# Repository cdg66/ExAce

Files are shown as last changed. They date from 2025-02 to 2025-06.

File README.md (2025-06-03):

# 📘 Project ExAce





> [!Warning]
>
> Content is not proven and suject to change without notice! Send to fab at your own risk. 

## 🧩 Overview

A tiny yet powerful fpga acceleration card designed with the Framework laptop expansion module system in mind.

## 🛠️ Features

- ✅ [CCGM1A1/2/4 compatible](https://colognechip.com/docs/ds1001-gatemate1-datasheet-latest.pdf)
- ✅ 20,480, 40,960 or 81,920 8-input LUT-trees.
- ✅ USB-type C, 5V 1.5A.
- ✅ Full access to SERDES via the USB-c connector (1 for A1/A2 and 2 for A4 device).
- ✅ USB2.0 interface is shared between the fpga and mcu via a USB mux.
- ✅ STM32L422RBI6 coprocessor and programmer.
- ✅ Shared Earth and i2c between the fpga and microcontroller for easier development.
- ✅ Free and Open-source FPGA toolchain!
- ✅ Lots of sensors!: PDM microphone, 6DoF imu, magnetometer, and thermometer.
- ✅ 8 user programmable led ideal for VU meters.
- ✅ 1 lvds IO ideal for connecting multiple board together in a cluster.
- 🔜 TinyFPGA-Bootloader support TBD.
- 🔜 DirtyJTAG support TBD.

---

## 💪 Application

- ✅ Machine learning
- ✅ Simulation
- ✅ Audio/Signal processing
- ✅ Retro Gaming
- ✅ Development platform

## 🗂️ Repository Structure

```bash
📁 /pcb-project-root
├── /3D_Models                    # 3D models of the PCB rendering
├── /Outputs/Fabrication          # Generated Gerber files, BOM and POS for fabrication
├── /PINOUT                       # STM32CubeMx for reference pinout
├── /Testbench/ExAceTestbench     # Testbench to break out serdes signals
├── /.gitignore
└── README.md
```

---

## 🧰 Tools & Dependencies

- **Design Software:** KiCad (v9.0.2 or higher)
- **MCU/FPGA Programmer:** ST-Link,Pico Dirty JTAG
- **Firmware Toolchain:** STM32CubeMX, arm toolchain, [Colonge chip open source toolchain](https://www.colognechip.com/docs/ug1002-toolchain-install-latest.pdf)  

---

## 🖼️ 3D view

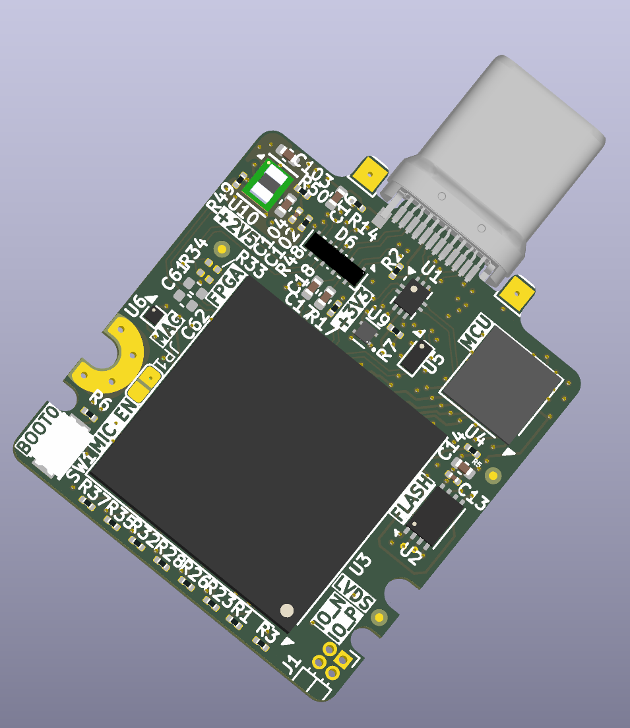
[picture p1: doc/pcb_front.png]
Front
  
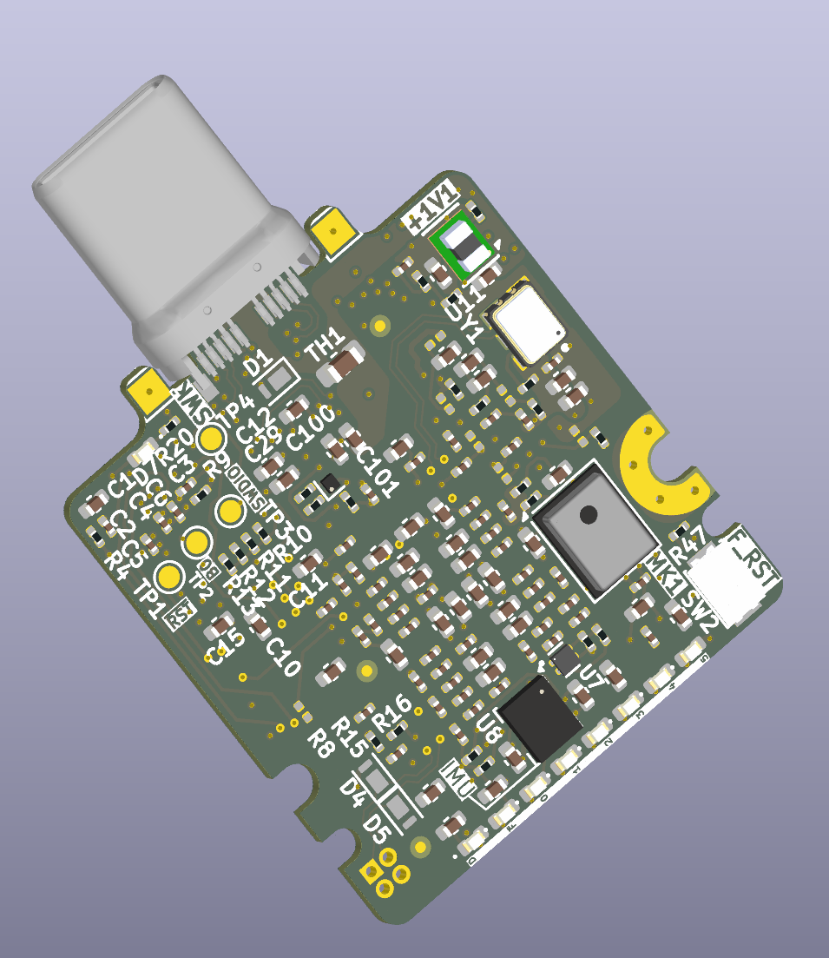
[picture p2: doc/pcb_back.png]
Back


---

## 🏗️ Getting Started

1. **Clone this repository**
   ```bash
   git clone https://github.com/cdg66/ExAce.git
   ```
2. **Open the project** in KiCad (navigate to `Expansion_Card_Retrofit.kicad_pro`)
3. **Modify / Build / Export Gerbers**

---

## 🚀 Fabrication

To get the board fabricated:

- Use the files in the `/Outputs` directory
- Recommended fabs:
  - [NextPcb](https://www.nextpcb.com/)
  - [JLCPCB](https://jlcpcb.com/) 

Stack-up:

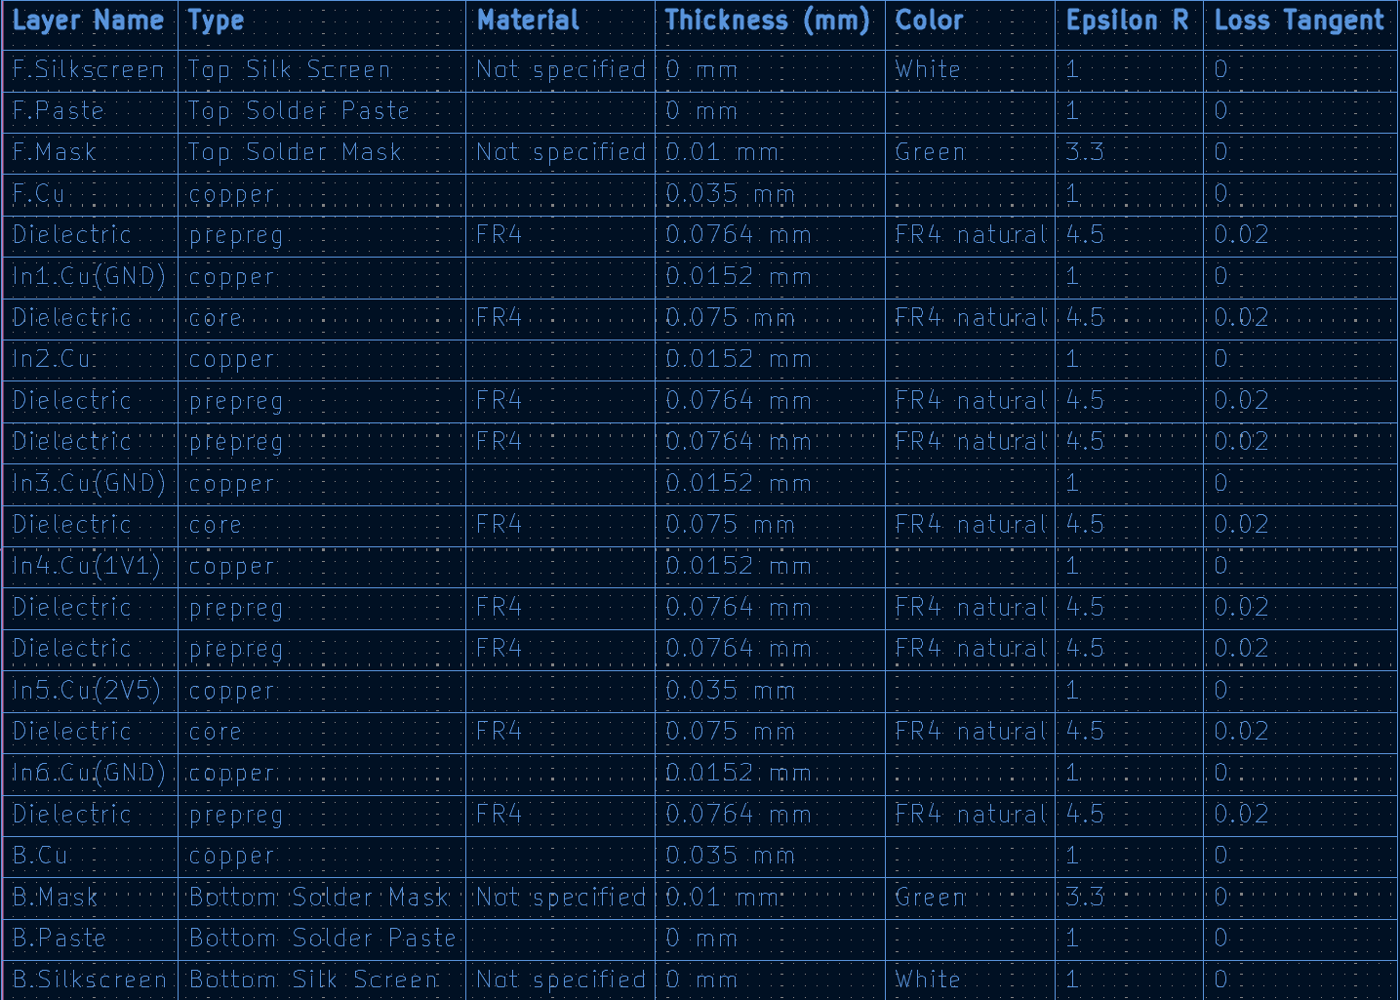
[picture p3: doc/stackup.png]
stackup


The recommended stack up is the JLC08081H-1080A at JLCPCB but can be done at any other PCB manufacturer.

---

## 🔧 License

This work is licensed under a [Creative Commons Attribution 4.0 International License](https://creativecommons.org/licenses/by/4.0/).

This project references and builds upon the open-source designs from  
[FrameworkComputer/ExpansionCards](https://github.com/FrameworkComputer/ExpansionCards),  
which is also licensed under the [Creative Commons Attribution 4.0 International License (CC-BY-4.0)](https://creativecommons.org/licenses/by/4.0/).

TPSM82822SILR

Footprint: Ultralibrarian

3D model: SnapMagic

Edited by me

S3A2505-100.000-L-X1-R

Symbol, Footprint, 3D model: SnapMagic

Edited by me

1054440011

3D model: Molex

KXT_331_LHS

3D model: SnapMagic

STM32L422RBI6

3D model: SnapMagic

TPS7A2033PDQNR

3D model: SnapMagic

---

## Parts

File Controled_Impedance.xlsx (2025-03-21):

Item # | Impedance type | Signal Layer | Reference Layer | Trace Width (mm) | trace Spacing | Required Impedance
1 | differential | Bottom | In1 | 0.09 | 0.3 | 100diff (+-10%)
1 | differential | Top | In6 | 0.09 | 0.3 | 100diff (+-10%)
1 | differential | In2 | In1-In3 | 0.09 | 0.3 | 100diff (+-10%)
1 | differential | Bottom | In1 | 0.1 | 0.2 | 90diff (+-10%)
1 | differential | Top | In6 | 0.1 | 0.2 | 91diff (+-10%)
1 | differential | In2 | In1-In3 | 0.1 | 0.2 | 92diff (+-10%)

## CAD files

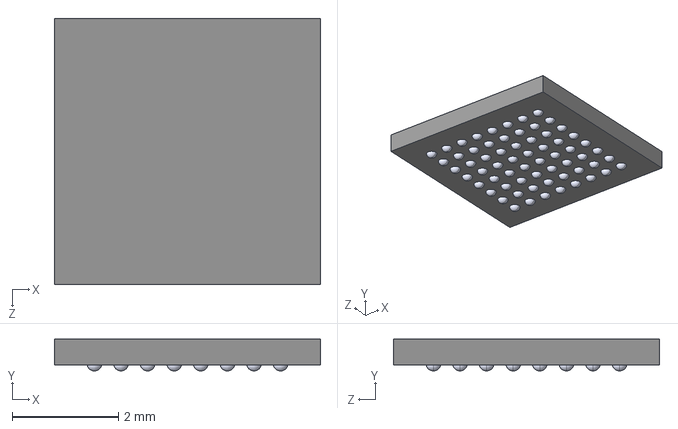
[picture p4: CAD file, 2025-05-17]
3D_Models/STM32L422RBI6.step
5.00 x 0.6 x 5.00 mm

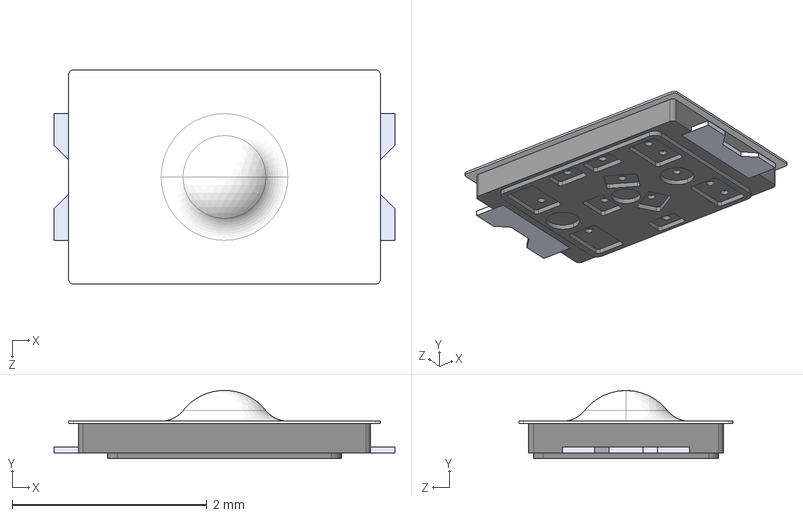
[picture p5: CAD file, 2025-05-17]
3D_Models/KXT_331_LHS.STEP
3.50 x 0.7 x 2.20 mm

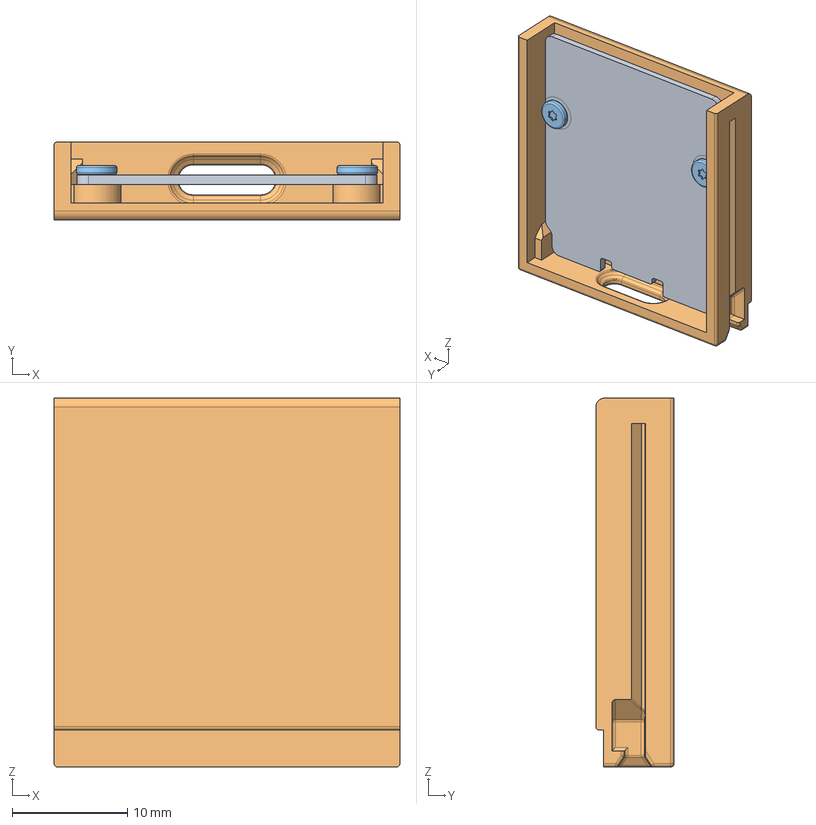
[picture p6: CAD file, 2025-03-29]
3D_Models/ExpansionCard_SelfTapping.stp
30.0 x 6.80 x 32.0 mm
FW_EXP_1USBC_FRAME_CLIP_BC_229_
STAR_SCREW_M2X3L_298_1 x 2

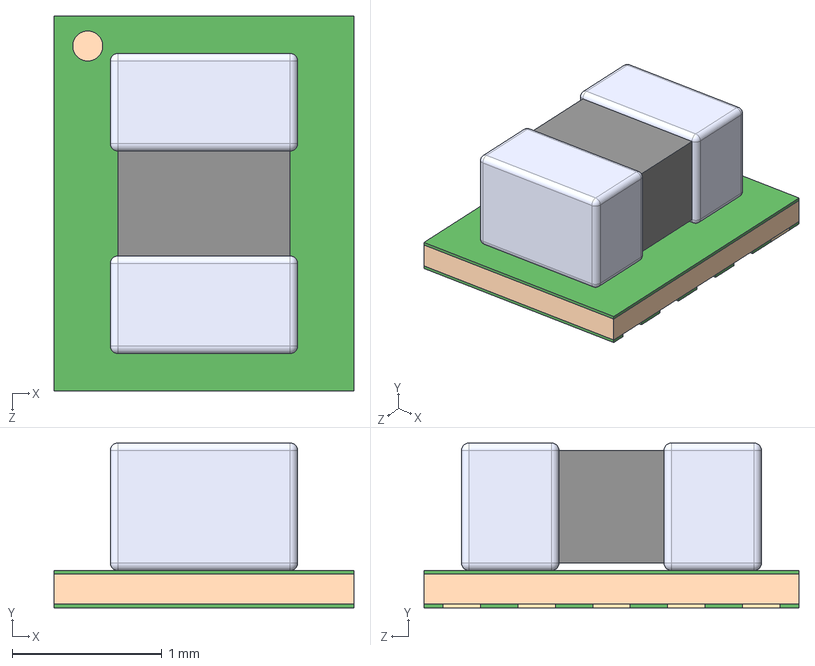
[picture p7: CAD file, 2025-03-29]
3D_Models/TPSM82822SILR.step
2.00 x 1.10 x 2.50 mm

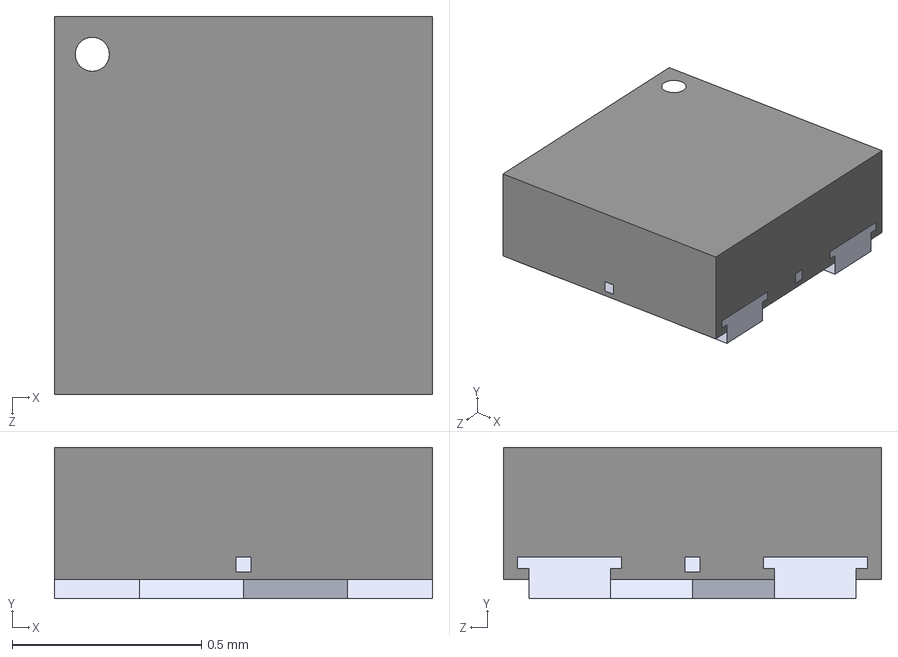
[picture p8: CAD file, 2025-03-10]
3D_Models/TPS7A2033PDQNR.step
1.00 x 0.4 x 1.00 mm

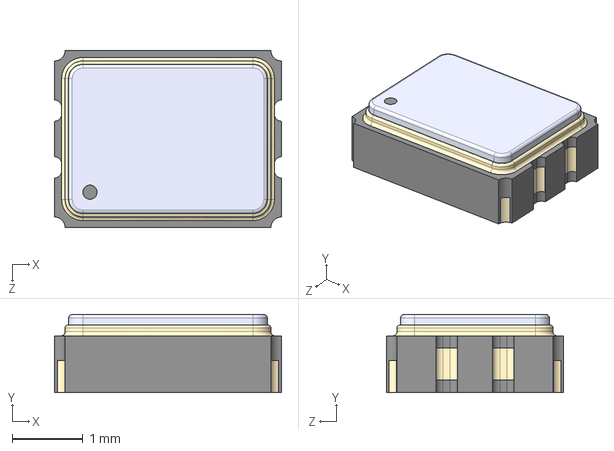
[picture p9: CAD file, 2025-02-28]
3D_Models/S3A2505-100.000-L-X1-R.step
3.20 x 1.10 x 2.50 mm

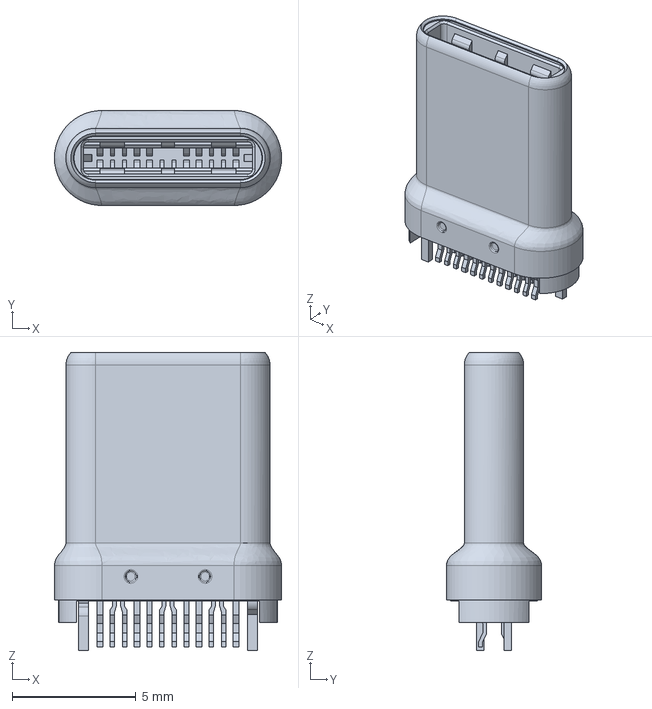
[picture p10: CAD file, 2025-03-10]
3D_Models/1054440011.stp
9.18 x 3.84 x 12.0 mm

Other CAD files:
3D_Models/ExpansionCard_SelfTapping.stl

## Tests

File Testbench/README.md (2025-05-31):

this is asimple board that breakout the SERDES pins out to SMA connectors for easy testing of the interface.

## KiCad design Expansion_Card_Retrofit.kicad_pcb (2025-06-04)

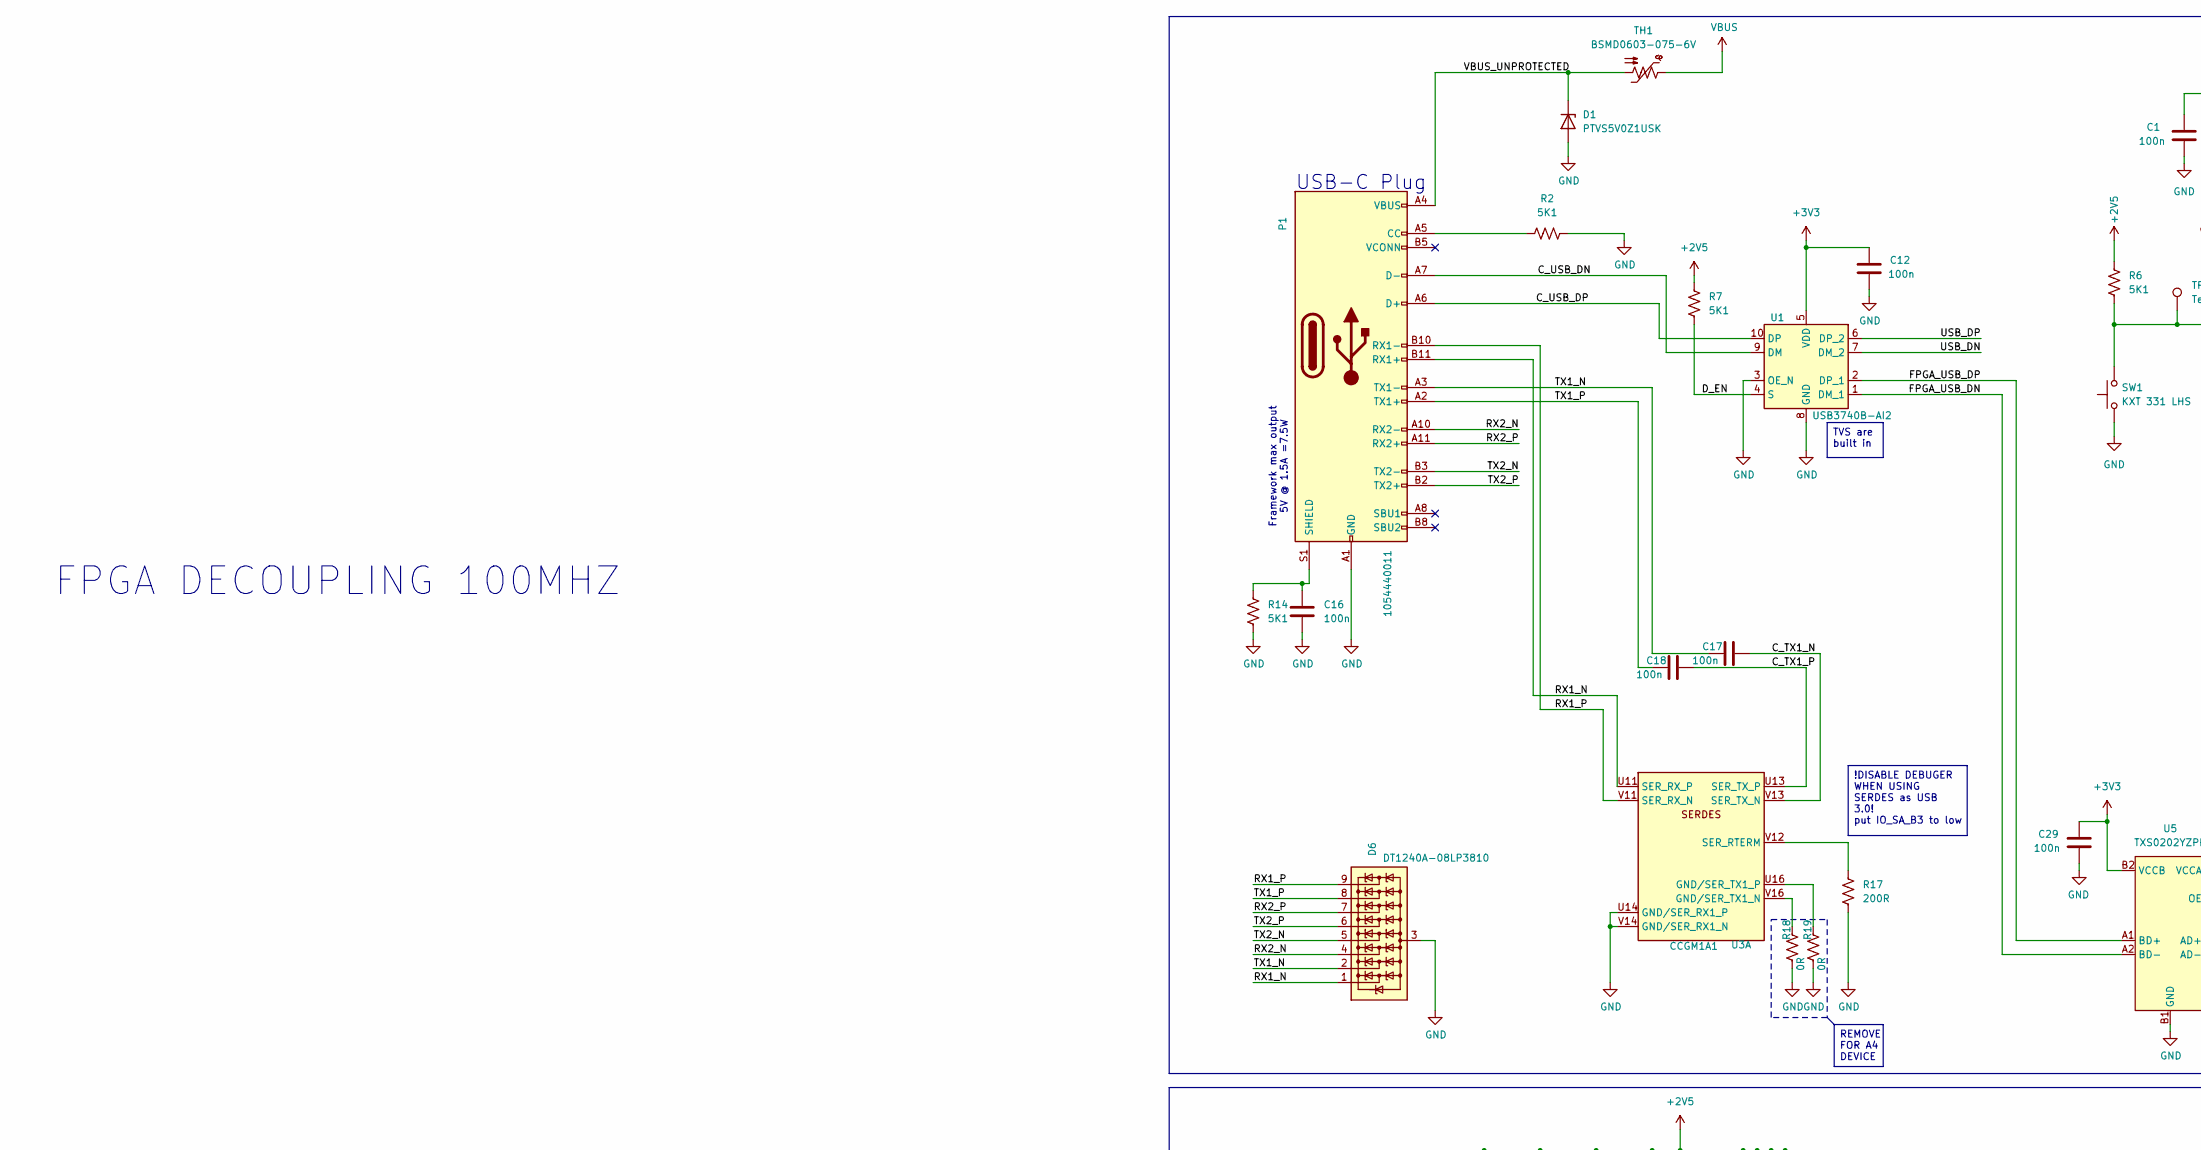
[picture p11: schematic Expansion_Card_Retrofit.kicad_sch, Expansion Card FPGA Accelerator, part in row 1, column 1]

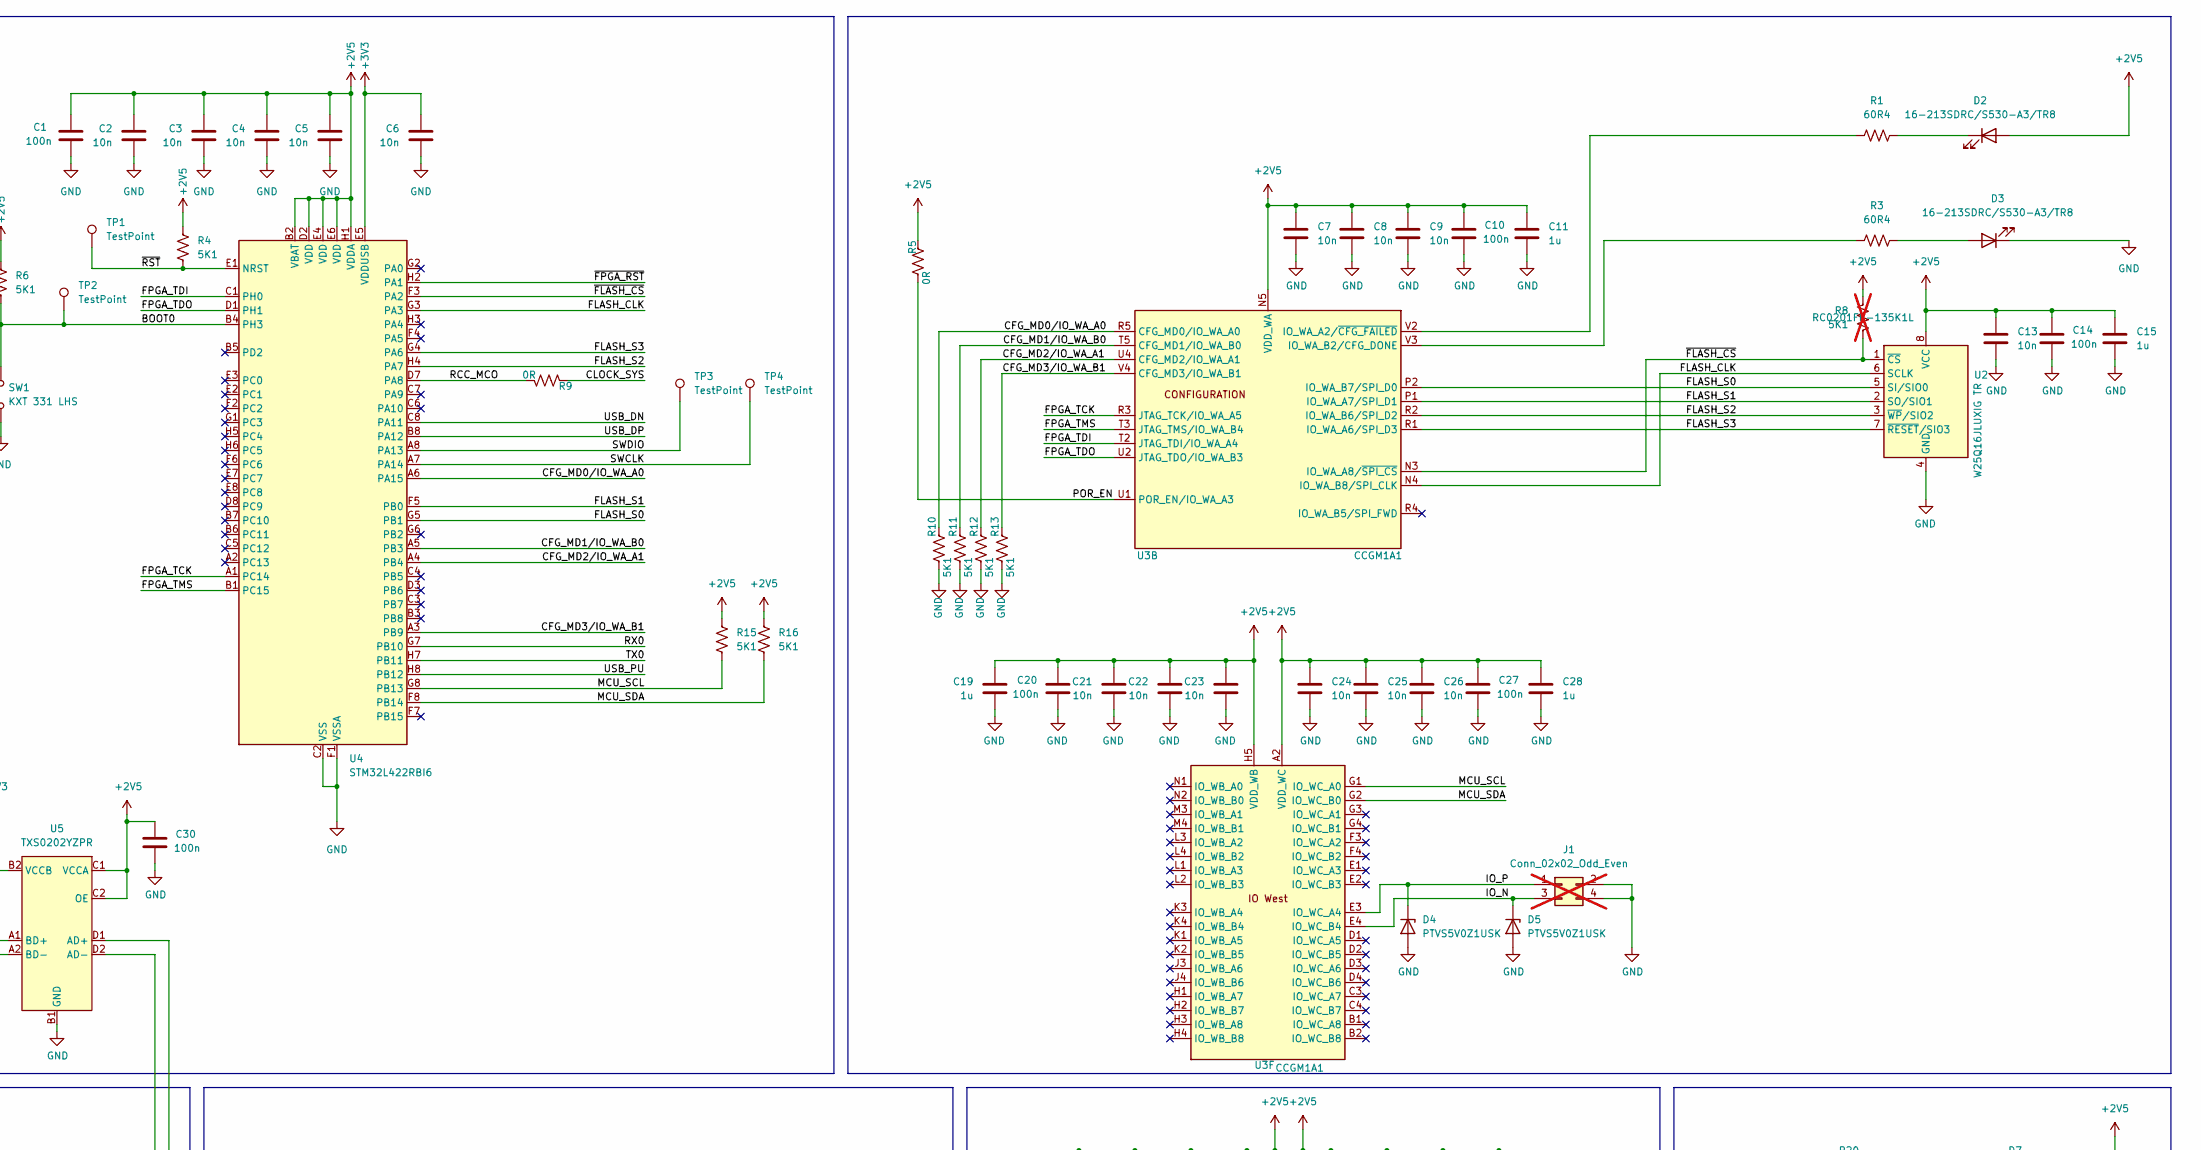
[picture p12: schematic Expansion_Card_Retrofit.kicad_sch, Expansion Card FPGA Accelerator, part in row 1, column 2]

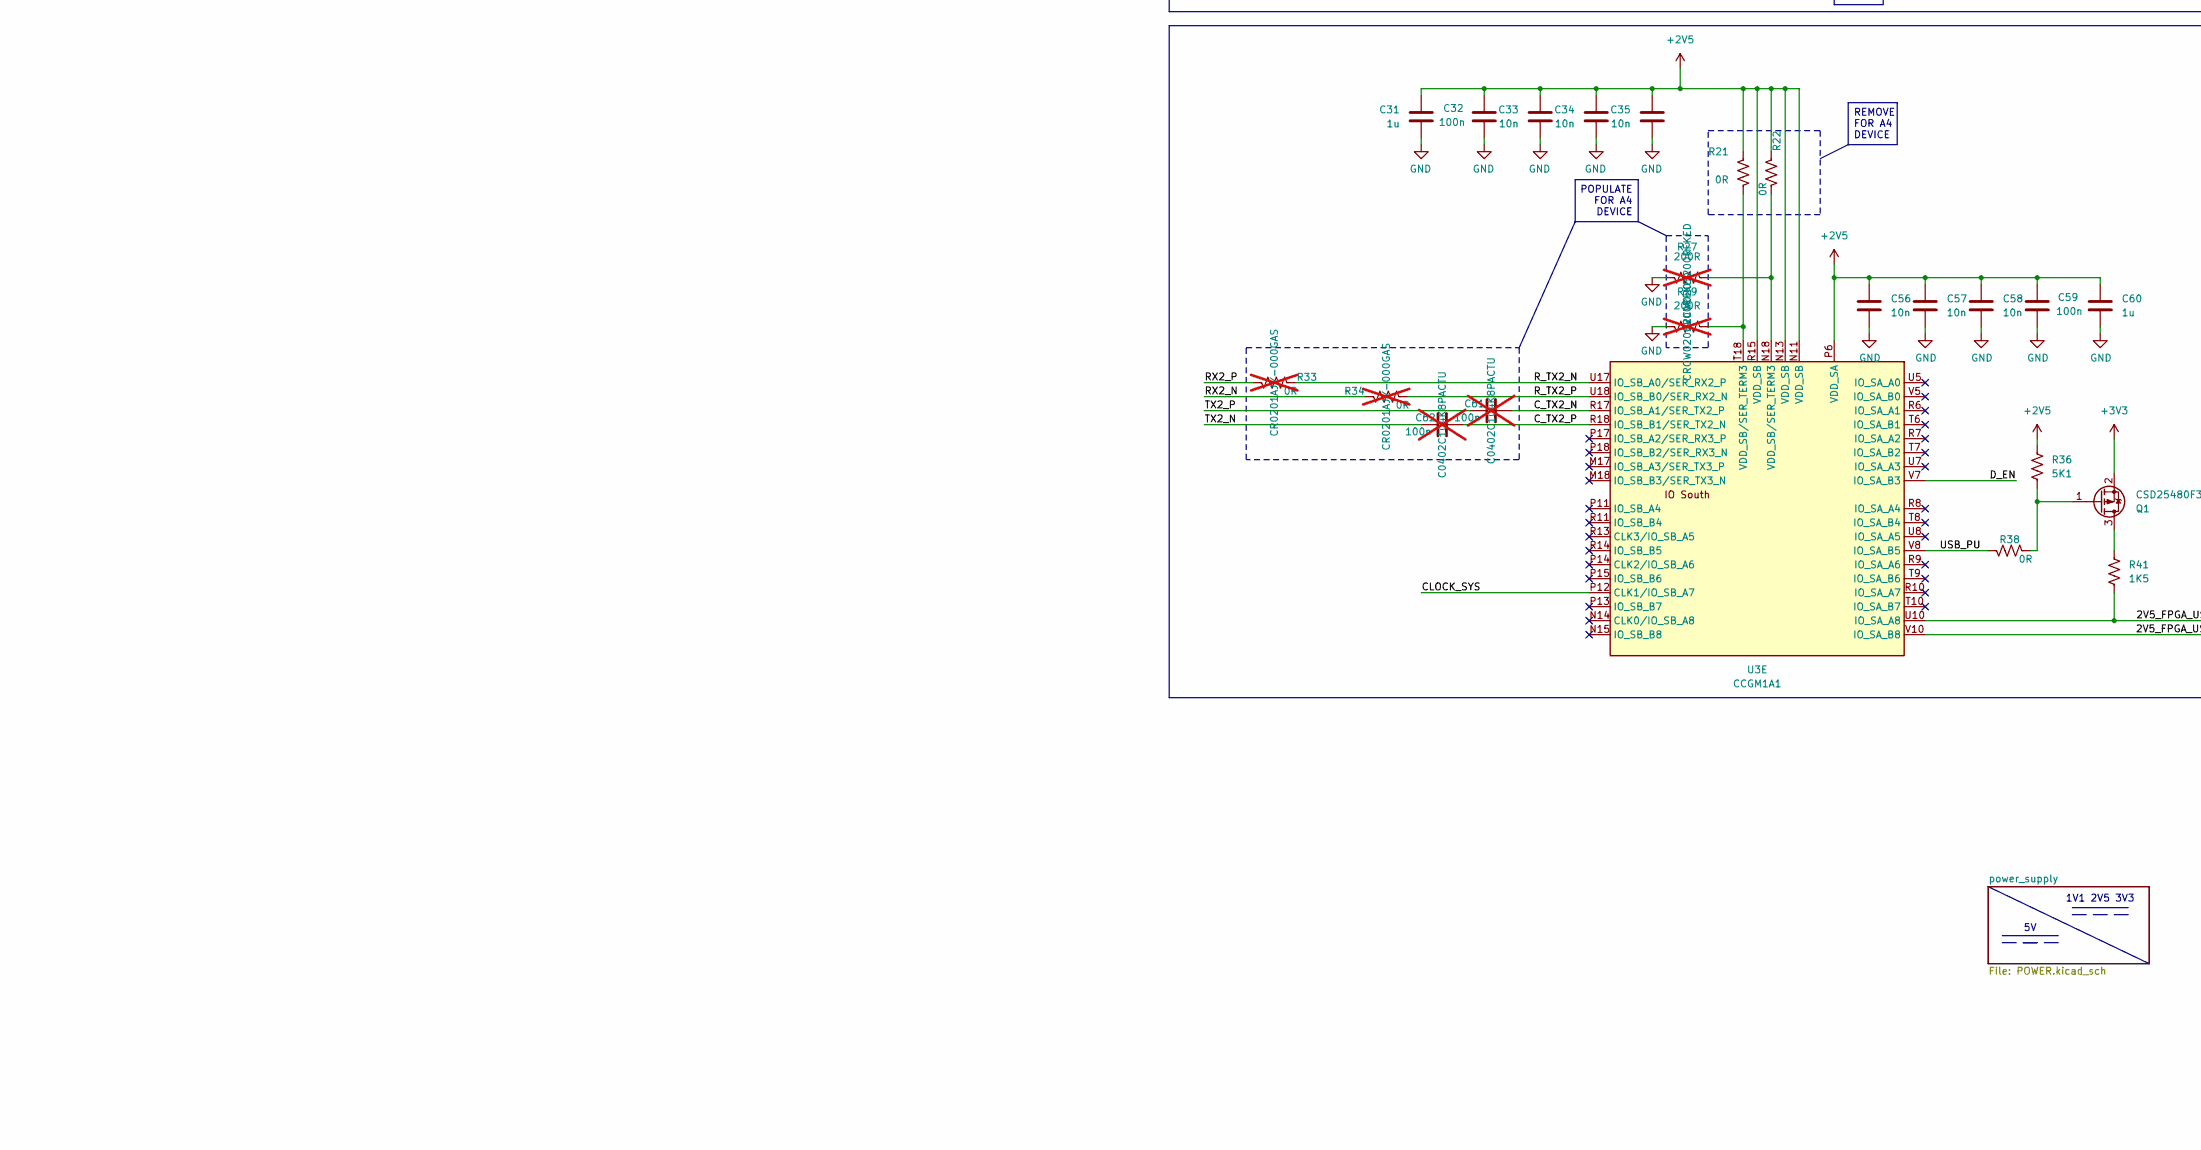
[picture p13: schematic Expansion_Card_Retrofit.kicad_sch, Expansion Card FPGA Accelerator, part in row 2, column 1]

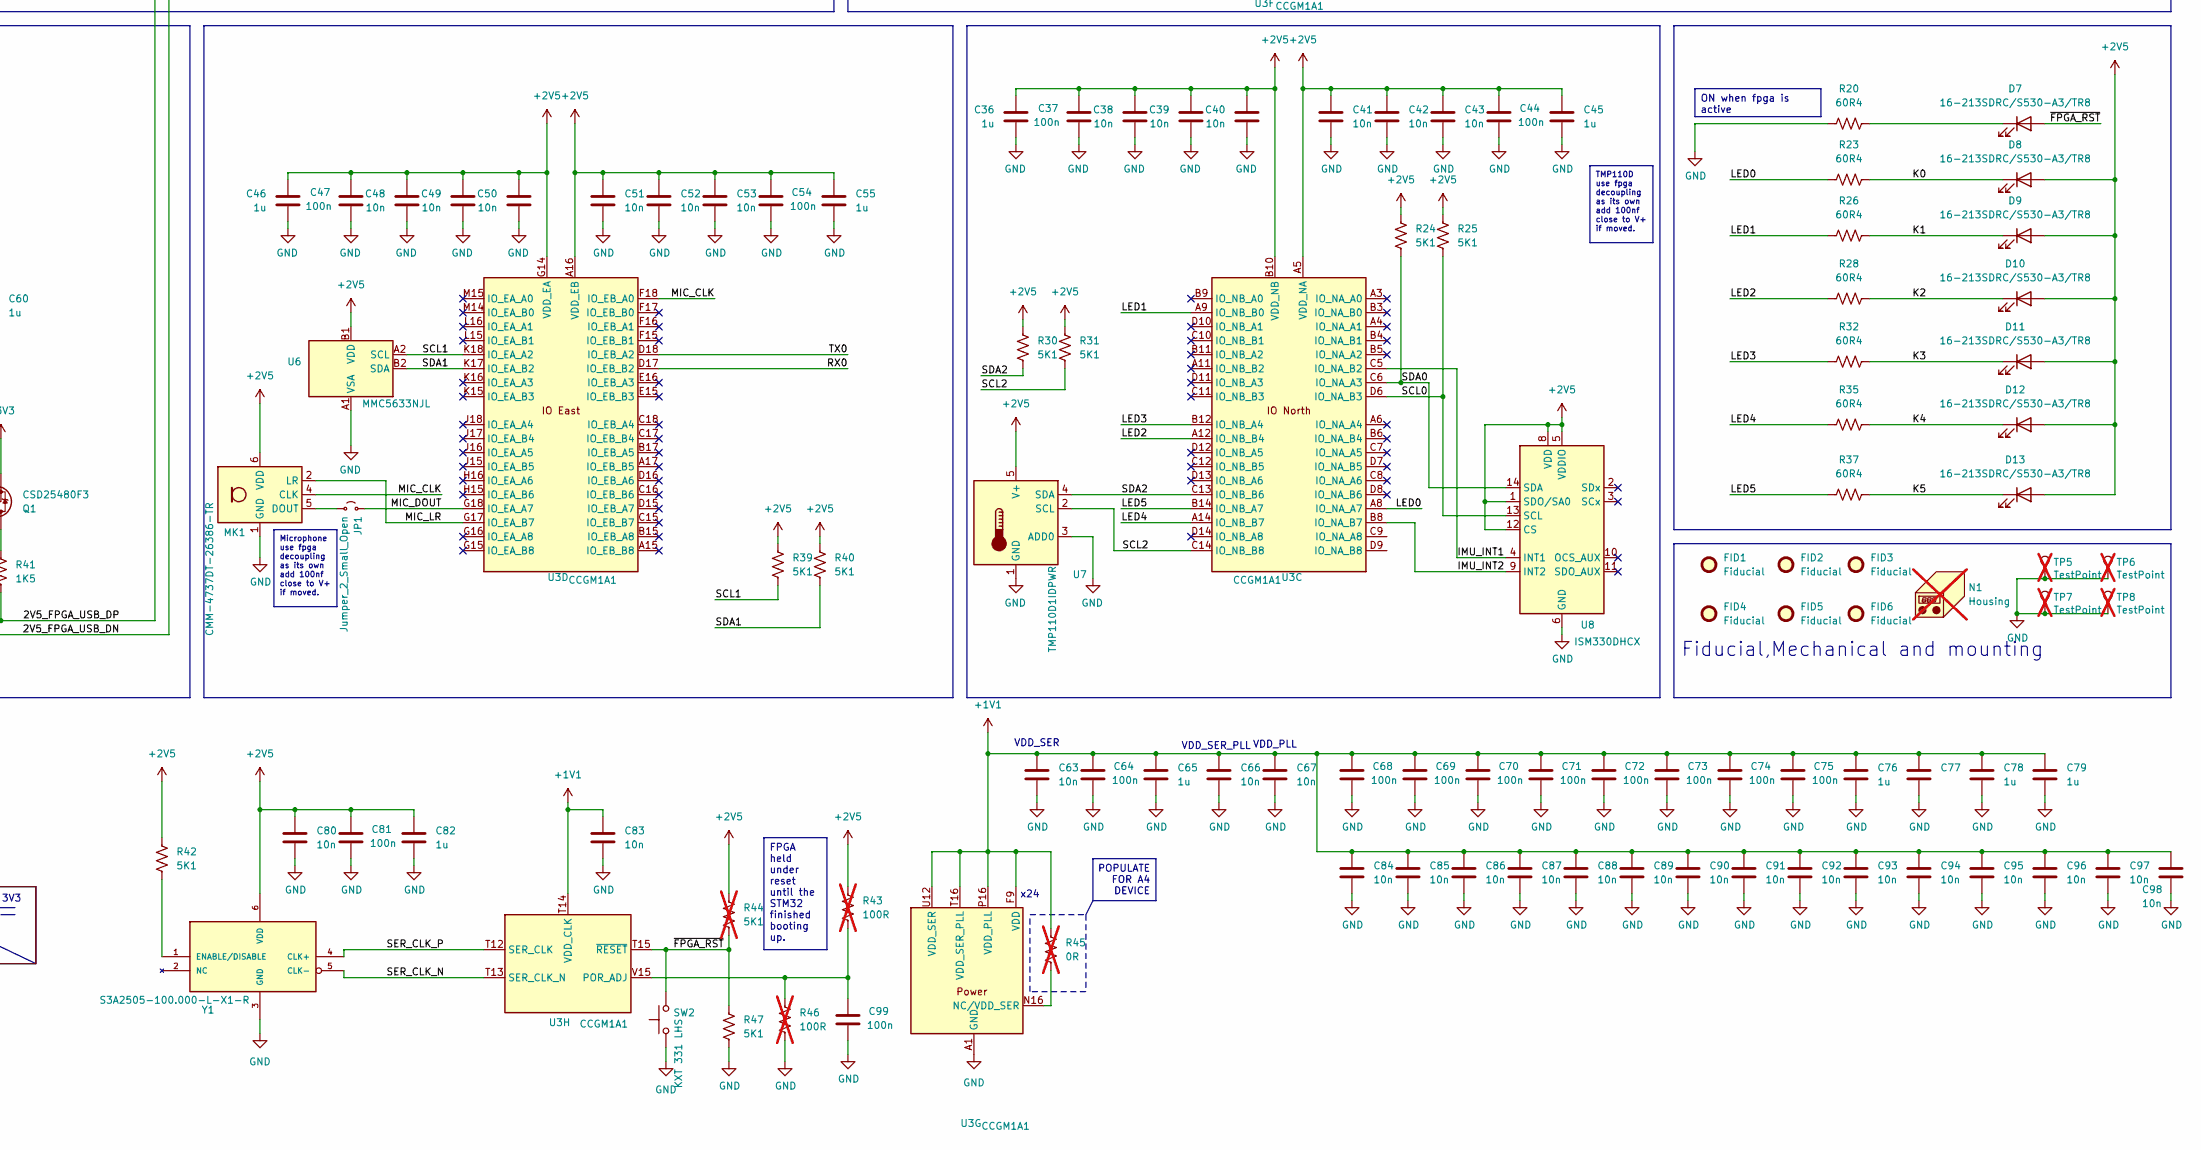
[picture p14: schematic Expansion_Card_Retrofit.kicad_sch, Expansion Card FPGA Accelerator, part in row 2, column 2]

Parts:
C1, C10, C12, C14, C16, C17, C18, C20, C27, C29, C30, C32, C37, C44, C47, C54, C59, C64, C68, C69, C70, C71, C72, C73, C74, C75, C81, C99: 100n; C_0402_1005Metric; MPN C0402C104K8PACTU
C2, C3, C4, C5, C6, C7, C8, C9, C13, C21, C22, C23, C24, C25, C26, C33, C34, C35, C38, C39, C40, C41, C42, C43, C48, C49, C50, C51, C52, C53, C56, C57, C58, C63, C66, C67, C80, C83, C84, C85, C86, C87, C88, C89, C90, C91, C92, C93, C94, C95, C96, C97, C98: 10n; C_0201_0603Metric; MPN C0201C103K4PACTU
C11, C15, C19, C28, C31, C36, C45, C46, C55, C60, C65, C76, C77, C78, C79, C82: 1u; C_0402_1005Metric; MPN CL05A105KA5NQNC
C61, C62: 100n; C_0402_1005Metric; MPN C0402C104K8PACTU; not fitted
D1, D4, D5: PTVS5V0Z1USK; Nexperia_DSN1608-2_1.6x0.8mm; MPN PTVS5V0Z1USKYL
D2, D3, D7, D8, D9, D10, D11, D12, D13: 16-213SDRC/S530-A3/TR8; LED_0402_1005Metric; MPN 16-213SDRC/S530-A3/TR8
D6: DT1240A-08LP3810; UDFN-9_1.0x3.8mm_P0.5mm; MPN DT1240A-08LP3810
FID1, FID2, FID3, FID4, FID5, FID6: Fiducial; Fiducial_0.5mm_Mask1mm; MPN DNP
J1: Conn_02x02_Odd_Even; PinHeader_2x02_P1.00mm_Horizontal; MPN DNP; not fitted
JP1: Jumper_2_Small_Open; Jumper_open; MPN DNP
MK1: CMM-4737DT-26386-TR; ST_HLGA-6_3.76x4.72mm_P1.65mm; MPN CMM-4737DT-26386-TR
N1: Housing; Enclosure; MPN DNP; not fitted
P1: 1054440011; USB_C_Plug_Molex_105444; MPN 1054440011
Q1: CSD25480F3; Texas_PicoStar_DFN-3_0.69x0.60mm; MPN CSD25480F3
R1, R3, R20, R23, R26, R28, R32, R35, R37: 60R4; R_0201_0603Metric; MPN RC0201FR-0760R4L
R2, R4, R6, R7, R10, R11, R12, R13, R14, R15, R16, R24, R25, R30, R31, R36, R39, R40, R42, R47: 5K1; R_0201_0603Metric; MPN RC0201FR-135K1L
R5, R9, R18, R19, R21, R22, R38: 0R; R_0201_0603Metric; MPN CR0201AJ/-000GAS
R8, R44: 5K1; R_0201_0603Metric; MPN RC0201FR-135K1L; not fitted
R17: 200R; R_0201_0603Metric; MPN CRCW0201200RFKED
R27, R29: 200R; R_0201_0603Metric; MPN CRCW0201200RFKED; not fitted
R33, R34, R45: 0R; R_0201_0603Metric; MPN CR0201AJ/-000GAS; not fitted
R41: 1K5; R_0201_0603Metric; MPN RC0201FR-071K5L
R43, R46: 100R; R_0201_0603Metric; MPN RC0201FR-07100RL; not fitted
SW1, SW2: KXT 331 LHS; SW_SPST_CK_KXT3; MPN KXT 331 LHS
TH1: BSMD0603-075-6V; C_0603_1608Metric; MPN PTSLR06038V075
TP1, TP2, TP3, TP4: TestPoint; TestPoint_Pad_D1.0mm; MPN DNP
TP5, TP6, TP7, TP8: TestPoint; TestPoint_Pad_1.5x1.5mm; MPN DNP; not fitted
U1: USB3740B-AI2; UQFN-10_1.3x1.8mm_P0.4mm; MPN USB3740B-AI2-TR
U2: W25Q16JLUXIG TR; Winbond_USON-8-1EP_3x2mm_P0.5mm_EP0.2x1.6mm; MPN W25Q32RVXHJQ TR
U3: CCGM1A1; BGA-324_15.0x15.0mm_Layout18x18_P0.8mm_Ball0.45mm_Pad0.4mm_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; MPN CCGM1A1-BGA324
U4: STM32L422RBI6; UFBGA-64_5x5mm_Layout8x8_P0.5mm; MPN STM32L422RBI6
U5: TXS0202YZPR; Texas_DSBGA-8_0.9x1.9mm_Layout2x4_P0.5mm; MPN TXS0202YZPR
U6: MMC5633NJL; WLP-4_0.86x0.86mm_P0.4mm; MPN MMC5633NJL
U7: TMP110D1IDPWR; Texas_X2SON-5_0.8x0.8mm_P0.48mm; MPN TMP110D
U8: ISM330DHCX; LGA-14_3x2.5mm_P0.5mm_LayoutBorder3x4y; MPN ISM330DHCXTR
Y1: S3A2505-100.000-L-X1-R; OSC_S3A2505-100.000-L-X1-R; PARTREV April 16,2024

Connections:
+1V1: C63.1, C64.1, C65.1, C66.1, C67.1, C68.1, C69.1, C70.1, C71.1, C72.1, C73.1, C74.1, C75.1, C76.1, C77.1, C78.1, C79.1, C83.1, C84.1, C85.1, C86.1, C87.1, C88.1, C89.1, C90.1, C91.1, C92.1, C93.1, C94.1, C95.1, C96.1, C97.1, C98.1, R45.1, U3.F9 (VDD), U3.G6 (VDD), U3.G8 (VDD), U3.G10 (VDD), U3.G12 (VDD), U3.H7 (VDD), U3.H9 (VDD), U3.H11 (VDD), U3.H13 (VDD), U3.J6 (VDD), U3.J8 (VDD), U3.J10 (VDD), U3.J12 (VDD), U3.K7 (VDD), U3.K9 (VDD), U3.K11 (VDD), U3.K13 (VDD), U3.L6 (VDD), U3.L8 (VDD), U3.L10 (VDD), U3.L12 (VDD), U3.M7 (VDD), U3.M9 (VDD), U3.M11 (VDD), U3.M13 (VDD), U3.N6 (VDD), U3.N8 (VDD), U3.N10 (VDD), U3.P16 (VDD_PLL), U3.T14 (VDD_CLK), U3.T16 (VDD_SER_PLL), U3.U12 (VDD_SER), U3.V17 (VDD_SER); also elsewhere on the board
+2V5: C1.1, C2.1, C3.1, C4.1, C5.1, C7.1, C8.1, C9.1, C10.1, C11.1, C13.1, C14.1, C15.1, C19.1, C20.1, C21.1, C22.1, C23.1, C24.1, C25.1, C26.1, C27.1, C28.1, C30.1, C31.1, C32.1, C33.1, C34.1, C35.1, C36.1, C37.1, C38.1, C39.1, C40.1, C41.1, C42.1, C43.1, C44.1, C45.1, C46.1, C47.1, C48.1, C49.1, C50.1, C51.1, C52.1, C53.1, C54.1, C55.1, C56.1, C57.1, C58.1, C59.1, C60.1, C80.1, C81.1, C82.1, D2.2 (A), D8.2 (A), D9.2 (A), D10.2 (A), D11.2 (A), D12.2 (A), D13.2 (A), MK1.6 (VDD), R4.1, R5.1, R6.1, R7.1, R8.1, R15.1, R16.1, R21.1, R22.1, R24.1, R25.1, R30.1, R31.1, R36.2, R39.1, R40.1, R42.1, R43.1, R44.1, U2.8 (VCC), U3.A2 (VDD_WC), U3.A5 (VDD_NA), U3.A16 (VDD_EB), U3.B7 (VDD_NA), U3.B10 (VDD_NB), U3.B13 (VDD_NB), U3.B18 (VDD_EB), U3.C2 (VDD_WC), U3.D5 (VDD_WC), U3.E6 (VDD_NA), U3.E8 (VDD_NA), U3.E10 (VDD_NB), U3.E12 (VDD_NB), U3.E14 (VDD_EB), U3.E17 (VDD_EB), U3.F2 (VDD_WC), U3.F5 (VDD_WC), U3.F7 (VDD_NA), U3.F11 (VDD_NB), U3.F13 (VDD_EB), U3.G14 (VDD_EA), U3.H5 (VDD_WB), U3.H17 (VDD_EA), U3.J2 (VDD_WB), U3.J14 (VDD_EA), U3.K5 (VDD_WB), U3.L14 (VDD_EA), U3.L17 (VDD_EA), U3.M2 (VDD_WB), U3.M5 (VDD_WB), U3.N5 (VDD_WA), U3.N11 (VDD_SB), U3.N13 (VDD_SB), U3.P3 (VDD_WA), U3.P5 (VDD_WA), U3.P6 (VDD_SA), U3.P8 (VDD_SA), U3.P10 (VDD_SA), U3.R15 (VDD_SB), U3.T1 (VDD_WA), U3.U3 (VDD_WA), U3.U6 (VDD_SA), U3.U9 (VDD_SA), U4.B2 (VBAT), U4.D2 (VDD), U4.E4 (VDD), U4.E6 (VDD), U4.H1 (VDDA), U5.C1 (VCCA), U5.C2 (OE), U6.B1 (VDD), U7.5 (V+), U8.1 (SDO/SA0), U8.5 (VDDIO), U8.8 (VDD), U8.12 (CS), Y1.6 (VDD); also elsewhere on the board
+3V3: C6.1, C12.1, C29.1, Q1.2 (S), U1.5 (VDD), U4.E5 (VDDUSB), U5.B2 (VCCB); also elsewhere on the board
/2V5_FPGA_USB_DN: U3.V10 (IO_SA_B8), U5.D1 (AD+)
/2V5_FPGA_USB_DP: R41.2, U3.U10 (IO_SA_A8), U5.D2 (AD-)
/BOOT0: R6.2, SW1.2, TP2.1, U4.B4 (PH3)
/CFG_MD0/IO_WA_A0: R10.1, U3.R5 (CFG_MD0/IO_WA_A0), U4.A6 (PA15)
/CFG_MD1/IO_WA_B0: R11.1, U3.T5 (CFG_MD1/IO_WA_B0), U4.A5 (PB3)
/CFG_MD2/IO_WA_A1: R12.1, U3.U4 (CFG_MD2/IO_WA_A1), U4.A4 (PB4)
/CFG_MD3/IO_WA_B1: R13.1, U3.V4 (CFG_MD3/IO_WA_B1), U4.A3 (PB9)
/CLOCK_SYS: R9.1, U3.P12 (CLK1/IO_SB_A7)
/C_TX1_N: C17.2, U3.V13 (SER_TX_N)
/C_TX1_P: C18.2, U3.U13 (SER_TX_P)
/C_TX2_N: C61.2, U3.R17 (IO_SB_A1/SER_TX2_P)
/C_TX2_P: C62.2, U3.R18 (IO_SB_B1/SER_TX2_N)
/C_USB_DN: P1.A7 (D-), U1.9 (DM)
/C_USB_DP: P1.A6 (D+), U1.10 (DP)
/D_EN: R7.2, U1.4 (S), U3.V7 (IO_SA_B3)
/FLASH_CLK: U2.6 (SCLK), U3.N4 (IO_WA_B8/SPI_CLK), U4.G3 (PA3)
/FLASH_S0: U2.5 (SI/SIO0), U3.P2 (IO_WA_B7/SPI_D0), U4.G5 (PB1)
/FLASH_S1: U2.2 (SO/SIO1), U3.P1 (IO_WA_A7/SPI_D1), U4.F5 (PB0)
/FLASH_S2: U2.3 (~WP/SIO2), U3.R2 (IO_WA_B6/SPI_D2), U4.H4 (PA7)
/FLASH_S3: U2.7 (~RESET/SIO3), U3.R1 (IO_WA_A6/SPI_D3), U4.G4 (PA6)
/FPGA_TCK: U3.R3 (JTAG_TCK/IO_WA_A5), U4.A1 (PC14)
/FPGA_TDI: U3.T2 (JTAG_TDI/IO_WA_A4), U4.C1 (PH0)
/FPGA_TDO: U3.U2 (JTAG_TDO/IO_WA_B3), U4.D1 (PH1)
/FPGA_TMS: U3.T3 (JTAG_TMS/IO_WA_B4), U4.B1 (PC15)
/FPGA_USB_DN: U1.1 (DM_1), U5.A2 (BD-)
/FPGA_USB_DP: U1.2 (DP_1), U5.A1 (BD+)
/IMU_INT1: U3.C5 (IO_NA_B2), U8.4 (INT1)
/IMU_INT2: U3.B8 (IO_NA_B7), U8.9 (INT2)
/IO_N: D5.1 (K), J1.3, U3.E4 (IO_WC_B4)
/IO_P: D4.1 (K), J1.1, U3.E3 (IO_WC_A4)
/K0: D8.1 (K), R23.2
/K1: D9.1 (K), R26.2
/K2: D10.1 (K), R28.2
/K3: D11.1 (K), R32.2
/K4: D12.1 (K), R35.2
/K5: D13.1 (K), R37.2
/LED0: R23.1, U3.A8 (IO_NA_A7)
/LED1: R26.1, U3.A9 (IO_NB_B0)
/LED2: R28.1, U3.A12 (IO_NB_B4)
/LED3: R32.1, U3.B12 (IO_NB_A4)
/LED4: R35.1, U3.A14 (IO_NB_B7)
/LED5: R37.1, U3.B14 (IO_NB_A7)
/MCU_SCL: R15.2, U3.G1 (IO_WC_A0), U4.G8 (PB13)
/MCU_SDA: R16.2, U3.G2 (IO_WC_B0), U4.F8 (PB14)
/MIC_CLK: MK1.4 (CLK), U3.F18 (IO_EB_A0)
/MIC_DOUT: JP1.2 (B), U3.G18 (IO_EA_A7)
/MIC_LR: MK1.2 (LR), U3.G17 (IO_EA_B7)
/POR_EN: R5.2, U3.U1 (POR_EN/IO_WA_A3)
/RCC_MCO: R9.2, U4.D7 (PA8)
/RX0: U3.D17 (IO_EB_B2), U4.G7 (PB10)
/RX1_N: D6.1 (K1), P1.B11 (RX1+), U3.U11 (SER_RX_P)
/RX1_P: D6.9 (K8), P1.B10 (RX1-), U3.V11 (SER_RX_N)
/RX2_N: D6.4 (K3), P1.A10 (RX2-), R34.1
/RX2_P: D6.7 (K6), P1.A11 (RX2+), R33.1
/R_TX2_N: R33.2, U3.U17 (IO_SB_A0/SER_RX2_P)
/R_TX2_P: R34.2, U3.U18 (IO_SB_B0/SER_RX2_N)
/SCL0: R25.2, U3.D6 (IO_NA_B3), U8.13 (SCL)
/SCL1: R39.2, U3.K18 (IO_EA_A2), U6.A2 (SCL)
/SCL2: R31.2, U3.C14 (IO_NB_B8), U7.2 (SCL)
/SDA0: R24.2, U3.C6 (IO_NA_A3), U8.14 (SDA)
/SDA1: R40.2, U3.K17 (IO_EA_B2), U6.B2 (SDA)
/SDA2: R30.2, U3.C13 (IO_NB_B6), U7.4 (SDA)
/SER_CLK_N: U3.T13 (SER_CLK_N), Y1.5 (CLK-)
/SER_CLK_P: U3.T12 (SER_CLK), Y1.4 (CLK+)
/SWCLK: TP4.1, U4.A7 (PA14)
/SWDIO: TP3.1, U4.A8 (PA13)
/TX0: U3.D18 (IO_EB_A2), U4.H7 (PB11)
/TX1_N: C17.1, D6.2 (K2), P1.A3 (TX1-)
/TX1_P: C18.1, D6.8 (K7), P1.A2 (TX1+)
/TX2_N: C62.1, D6.5 (K4), P1.B3 (TX2-)
/TX2_P: C61.1, D6.6 (K5), P1.B2 (TX2+)
/USB_DN: U1.7 (DM_2), U4.C8 (PA11)
/USB_DP: U1.6 (DP_2), U4.B8 (PA12)
/USB_PU: R38.1, U3.V8 (IO_SA_B5), U4.H8 (PB12)
/VBUS_UNPROTECTED: D1.1 (K), P1.A4 (VBUS), P1.A9 (VBUS), P1.B4 (VBUS), P1.B9 (VBUS), TH1.2
/~FLASH_CS: R8.2, U2.1 (~CS), U3.N3 (IO_WA_A8/~SPI_CS), U4.F3 (PA2)
/~FPGA_RST: D7.2 (A), R44.2, R47.1, SW2.2, U3.T15 (~RESET), U4.H2 (PA1)
/~RST: R4.2, TP1.1, U4.E1 (NRST)
GND: C1.2, C2.2, C3.2, C4.2, C5.2, C6.2, C7.2, C8.2, C9.2, C10.2, C11.2, C12.2, C13.2, C14.2, C15.2, C16.2, C19.2, C20.2, C21.2, C22.2, C23.2, C24.2, C25.2, C26.2, C27.2, C28.2, C29.2, C30.2, C31.2, C32.2, C33.2, C34.2, C35.2, C36.2, C37.2, C38.2, C39.2, C40.2, C41.2, C42.2, C43.2, C44.2, C45.2, C46.2, C47.2, C48.2, C49.2, C50.2, C51.2, C52.2, C53.2, C54.2, C55.2, C56.2, C57.2, C58.2, C59.2, C60.2, C63.2, C64.2, C65.2, C66.2, C67.2, C68.2, C69.2, C70.2, C71.2, C72.2, C73.2, C74.2, C75.2, C76.2, C77.2, C78.2, C79.2, C80.2, C81.2, C82.2, C83.2, C84.2, C85.2, C86.2, C87.2, C88.2, C89.2, C90.2, C91.2, C92.2, C93.2, C94.2, C95.2, C96.2, C97.2, C98.2, C99.2, D1.2 (A), D3.1 (K), D4.2 (A), D5.2 (A), D6.3 (A), J1.2, J1.4, MK1.1 (GND), MK1.3 (GND), P1.A1 (GND), P1.A12 (GND), P1.B1 (GND), P1.B12 (GND), R2.2, R10.2, R11.2, R12.2, R13.2, R14.2, R17.2, R18.2, R19.2, R20.1, R27.1, R29.1, R46.2, R47.2, SW1.1, SW2.1, TP5.1, TP6.1, TP7.1, TP8.1, U1.3 (OE_N), U1.8 (GND), U2.4 (GND), U2.9 (GND), U3.A1 (GND), U3.A7 (GND), U3.A10 (GND), U3.A13 (GND), U3.A18 (GND), U3.B16 (GND), U3.C1 (GND), U3.E5 (GND), U3.E7 (GND), U3.E9 (GND), U3.E11 (GND), U3.E13 (GND), U3.E18 (GND), U3.F1 (GND), U3.F6 (GND), U3.F8 (GND), U3.F10 (GND), U3.F12 (GND), U3.F14 (GND), U3.G5 (GND), U3.G7 (GND), U3.G9 (GND), U3.G11 (GND), U3.G13 (GND), U3.H6 (GND), U3.H8 (GND), U3.H10 (GND), U3.H12 (GND), U3.H14 (GND), U3.H18 (GND), U3.J1 (GND), U3.J5 (GND), U3.J7 (GND), U3.J9 (GND), U3.J11 (GND), U3.J13 (GND), U3.K6 (GND), U3.K8 (GND), U3.K10 (GND), U3.K12 (GND), U3.K14 (GND), U3.L5 (GND), U3.L7 (GND), U3.L9 (GND), U3.L11 (GND), U3.L13 (GND), U3.L18 (GND), U3.M1 (GND), U3.M6 (GND), U3.M8 (GND), U3.M10 (GND), U3.M12 (GND), U3.M16 (GND), U3.N7 (GND), U3.N9 (GND), U3.N12 (GND), U3.N17 (GND), U3.P4 (GND), U3.P7 (GND), U3.P9 (GND), U3.R12 (GND), U3.R16 (GND), U3.T4 (GND), U3.T11 (GND), U3.T17 (GND), U3.U14 (GND/SER_RX1_P), U3.U15 (GND), U3.V1 (GND), U3.V6 (GND), U3.V9 (GND), U3.V14 (GND/SER_RX1_N), U3.V18 (GND), U4.C2 (VSS), U4.D4 (VSS), U4.D5 (VSS), U4.D6 (VSS), U4.F1 (VSSA), U5.B1 (GND), U6.A1 (VSA), U7.1 (GND), U7.3 (ADD0), U8.6 (GND), U8.7 (GND), Y1.3 (GND); also elsewhere on the board
unnamed: D2.1 (K), R1.2
unnamed: D3.2 (A), R3.2
unnamed: D7.1 (K), R20.2
unnamed: JP1.1 (A), MK1.5 (DOUT)
unnamed: P1.A5 (CC), R2.1
unnamed: C16.1, P1.S1 (SHIELD), R14.1
unnamed: Q1.3 (D), R41.1
unnamed: Q1.1 (G), R36.1, R38.2
unnamed: R21.2, R29.2, U3.T18 (VDD_SB/SER_TERM3)
unnamed: R22.2, R27.2, U3.N18 (VDD_SB/SER_TERM3)
unnamed: R18.1, U3.V16 (GND/SER_TX1_N)
unnamed: R19.1, U3.U16 (GND/SER_TX1_P)
unnamed: R17.1, U3.V12 (SER_RTERM)
unnamed: R1.1, U3.V2 (IO_WA_A2/~CFG_FAILED)
unnamed: R3.1, U3.V3 (IO_WA_B2/CFG_DONE)
unnamed: R45.2, U3.N16 (NC/VDD_SER)
unnamed: C99.1, R43.2, R46.1, U3.V15 (POR_ADJ)
unnamed: R42.2, Y1.1 (ENABLE/DISABLE)
VBUS: TH1.1; also elsewhere on the board

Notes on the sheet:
Fiducial,Mechanical and mounting
VDD_PLL
x24
Framework max output 5V @ 1.5A =7.5W
FPGA DECOUPLING 100MHZ
USB-C Plug
1V1 2V5 3V3
VDD_SER
VDD_SER_PLL
!DISABLE DEBUGER WHEN USING SERDES as USB 3.0! put IO_SA_B3 to low
FPGA held under reset until the STM32 finished booting up.
ON when fpga is active
POPULATE FOR A4 DEVICE
Microphone use fpga decoupling as its own add 100nf close to V+ if moved.
TVS are built in
REMOVE FOR A4 DEVICE
TMP110D use fpga decoupling as its own add 100nf close to V+ if moved.

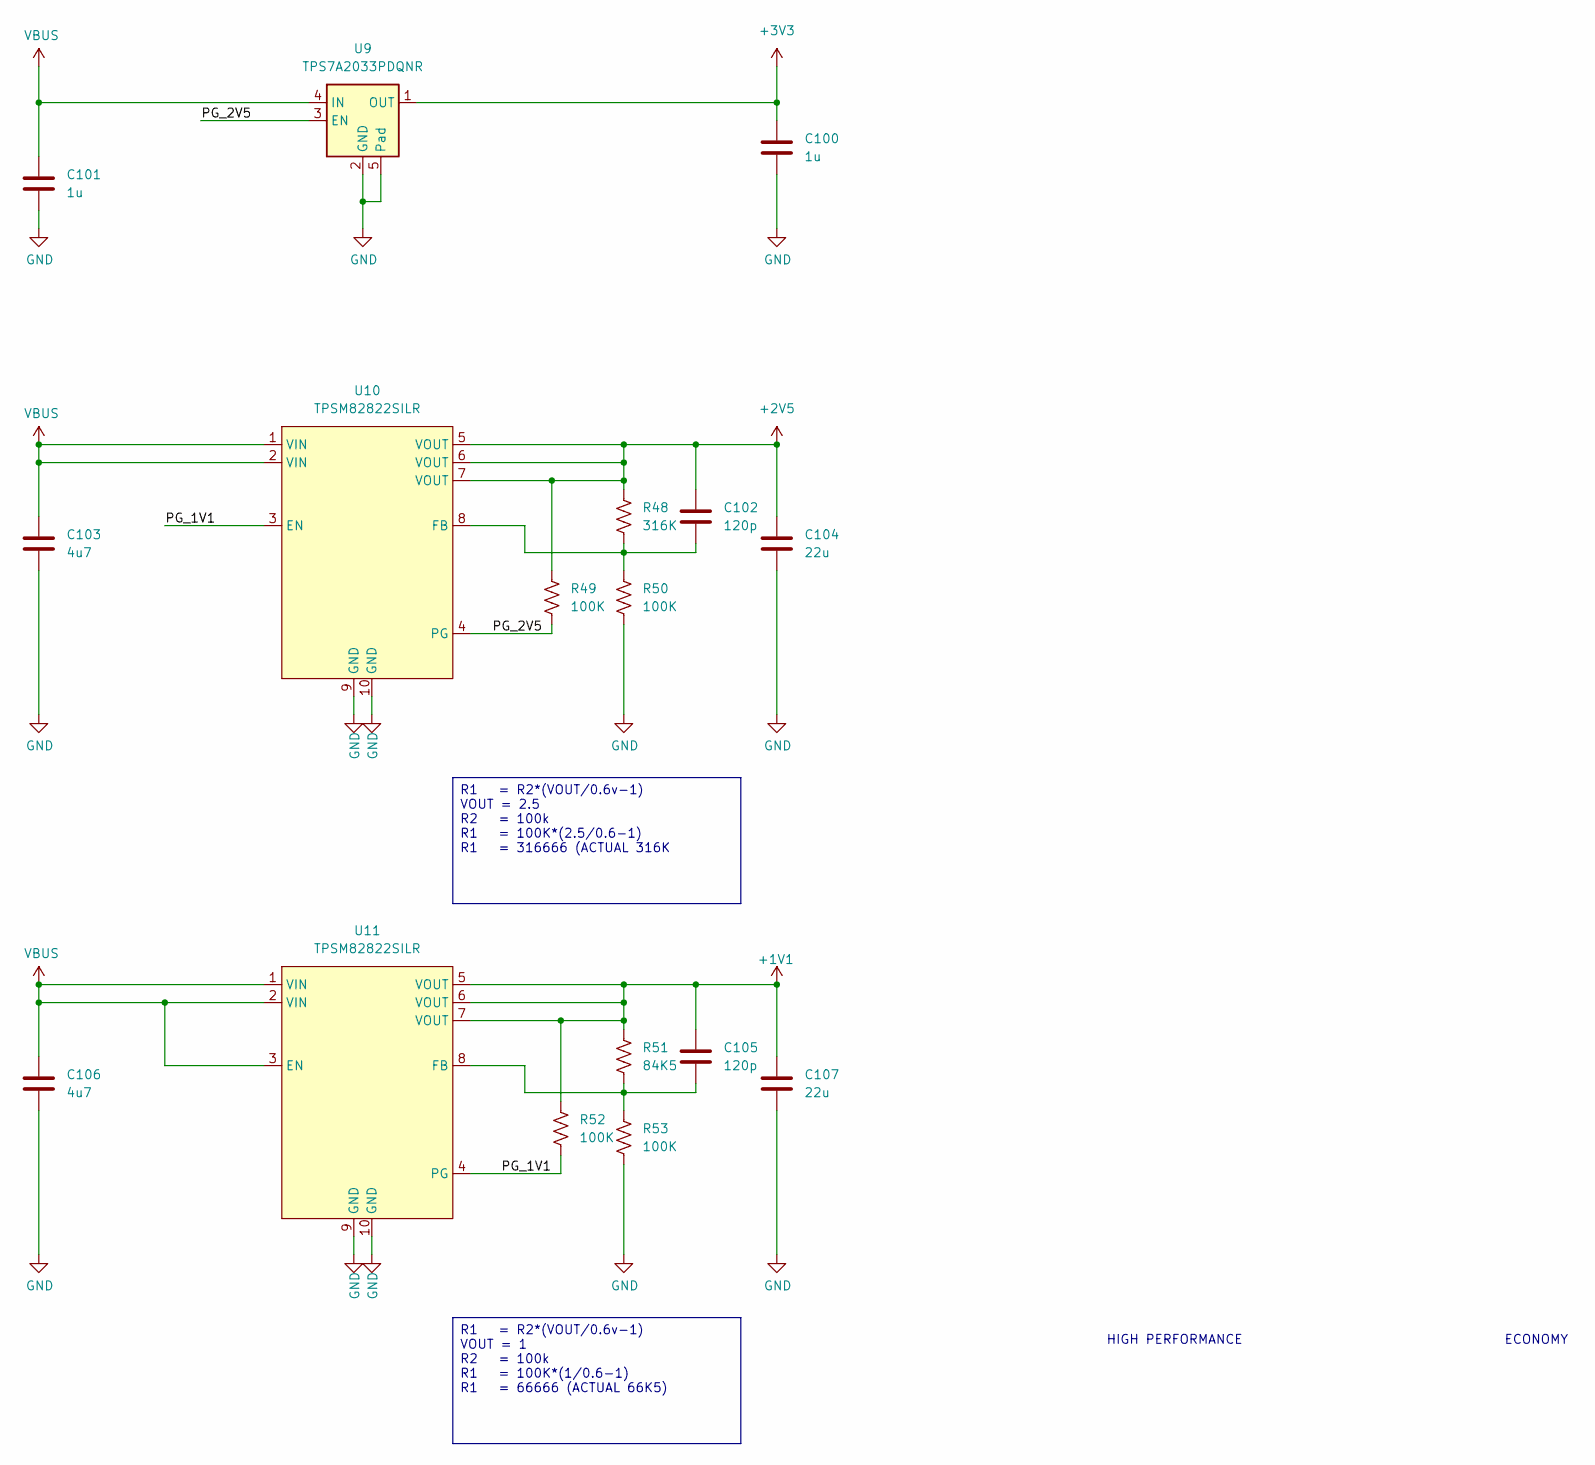
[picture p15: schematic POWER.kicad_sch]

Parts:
C100, C101: 1u; C_0402_1005Metric; MPN CL05A105KA5NQNC
C102, C105: 120p; C_0201_0603Metric; MPN GRM033R71E121KA01D
C103, C106: 4u7; C_0402_1005Metric; MPN GRM155C61E475ME15D
C104, C107: 22u; C_0402_1005Metric; MPN GMC04X5R226M10NT
R48: 316K; R_0201_0603Metric; MPN RC0201FR-07316KL
R49, R50, R52, R53: 100K; R_0201_0603Metric; MPN RC0201FR-07100KL
R51: 84K5; R_0201_0603Metric; MPN RC0201FR-0784K5L
U9: TPS7A2033PDQNR; Texas_X2SON-4_1x1mm_P0.65mm; MPN TPS7A2033PDQNR
U10, U11: TPSM82822SILR; SIL0010D-MFG; MPN TPSM82822SILR

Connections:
+1V1: C105.1, C107.1, R51.1, R52.1, U11.5 (VOUT), U11.6 (VOUT), U11.7 (VOUT); also elsewhere on the board
+2V5: C102.1, C104.1, R48.1, R49.1, U10.5 (VOUT), U10.6 (VOUT), U10.7 (VOUT); also elsewhere on the board
+3V3: C100.1, U9.1 (OUT); also elsewhere on the board
/power_supply/PG_1V1: R52.2, U10.3 (EN), U11.4 (PG)
/power_supply/PG_2V5: R49.2, U9.3 (EN), U10.4 (PG)
GND: C100.2, C101.2, C103.2, C104.2, C106.2, C107.2, R50.2, R53.2, U9.2 (GND), U9.5 (Pad), U10.9 (GND), U10.10 (GND), U11.9 (GND), U11.10 (GND); also elsewhere on the board
unnamed: C102.2, R48.2, R50.1, U10.8 (FB)
unnamed: C105.2, R51.2, R53.1, U11.8 (FB)
VBUS: C101.1, C103.1, C106.1, U9.4 (IN), U10.1 (VIN), U10.2 (VIN), U11.1 (VIN), U11.2 (VIN), U11.3 (EN); also elsewhere on the board

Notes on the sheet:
ECONOMY
HIGH PERFORMANCE
R1 = R2*(VOUT/0.6v-1) VOUT = 1 R2 = 100k R1 = 100K*(1/0.6-1) R1 = 66666 (ACTUAL 66K5)
R1 = R2*(VOUT/0.6v-1) VOUT = 2.5 R2 = 100k R1 = 100K*(2.5/0.6-1) R1 = 316666 (ACTUAL 316K

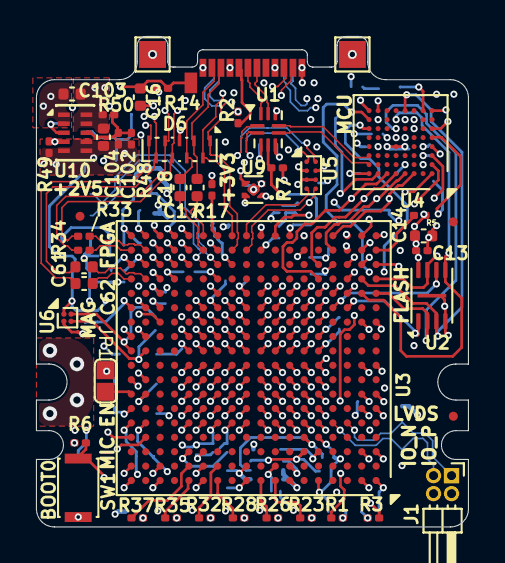
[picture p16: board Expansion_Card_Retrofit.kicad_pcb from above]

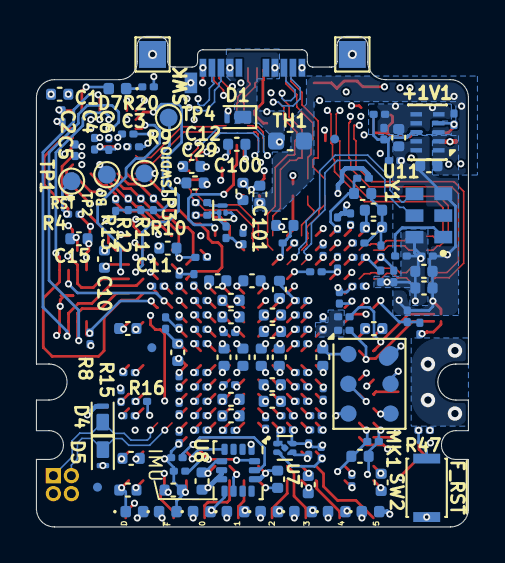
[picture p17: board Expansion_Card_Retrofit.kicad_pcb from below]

Board: 8 copper layers, 24.0 x 27.3 mm, 207 parts (160 on the bottom side), 105 nets.

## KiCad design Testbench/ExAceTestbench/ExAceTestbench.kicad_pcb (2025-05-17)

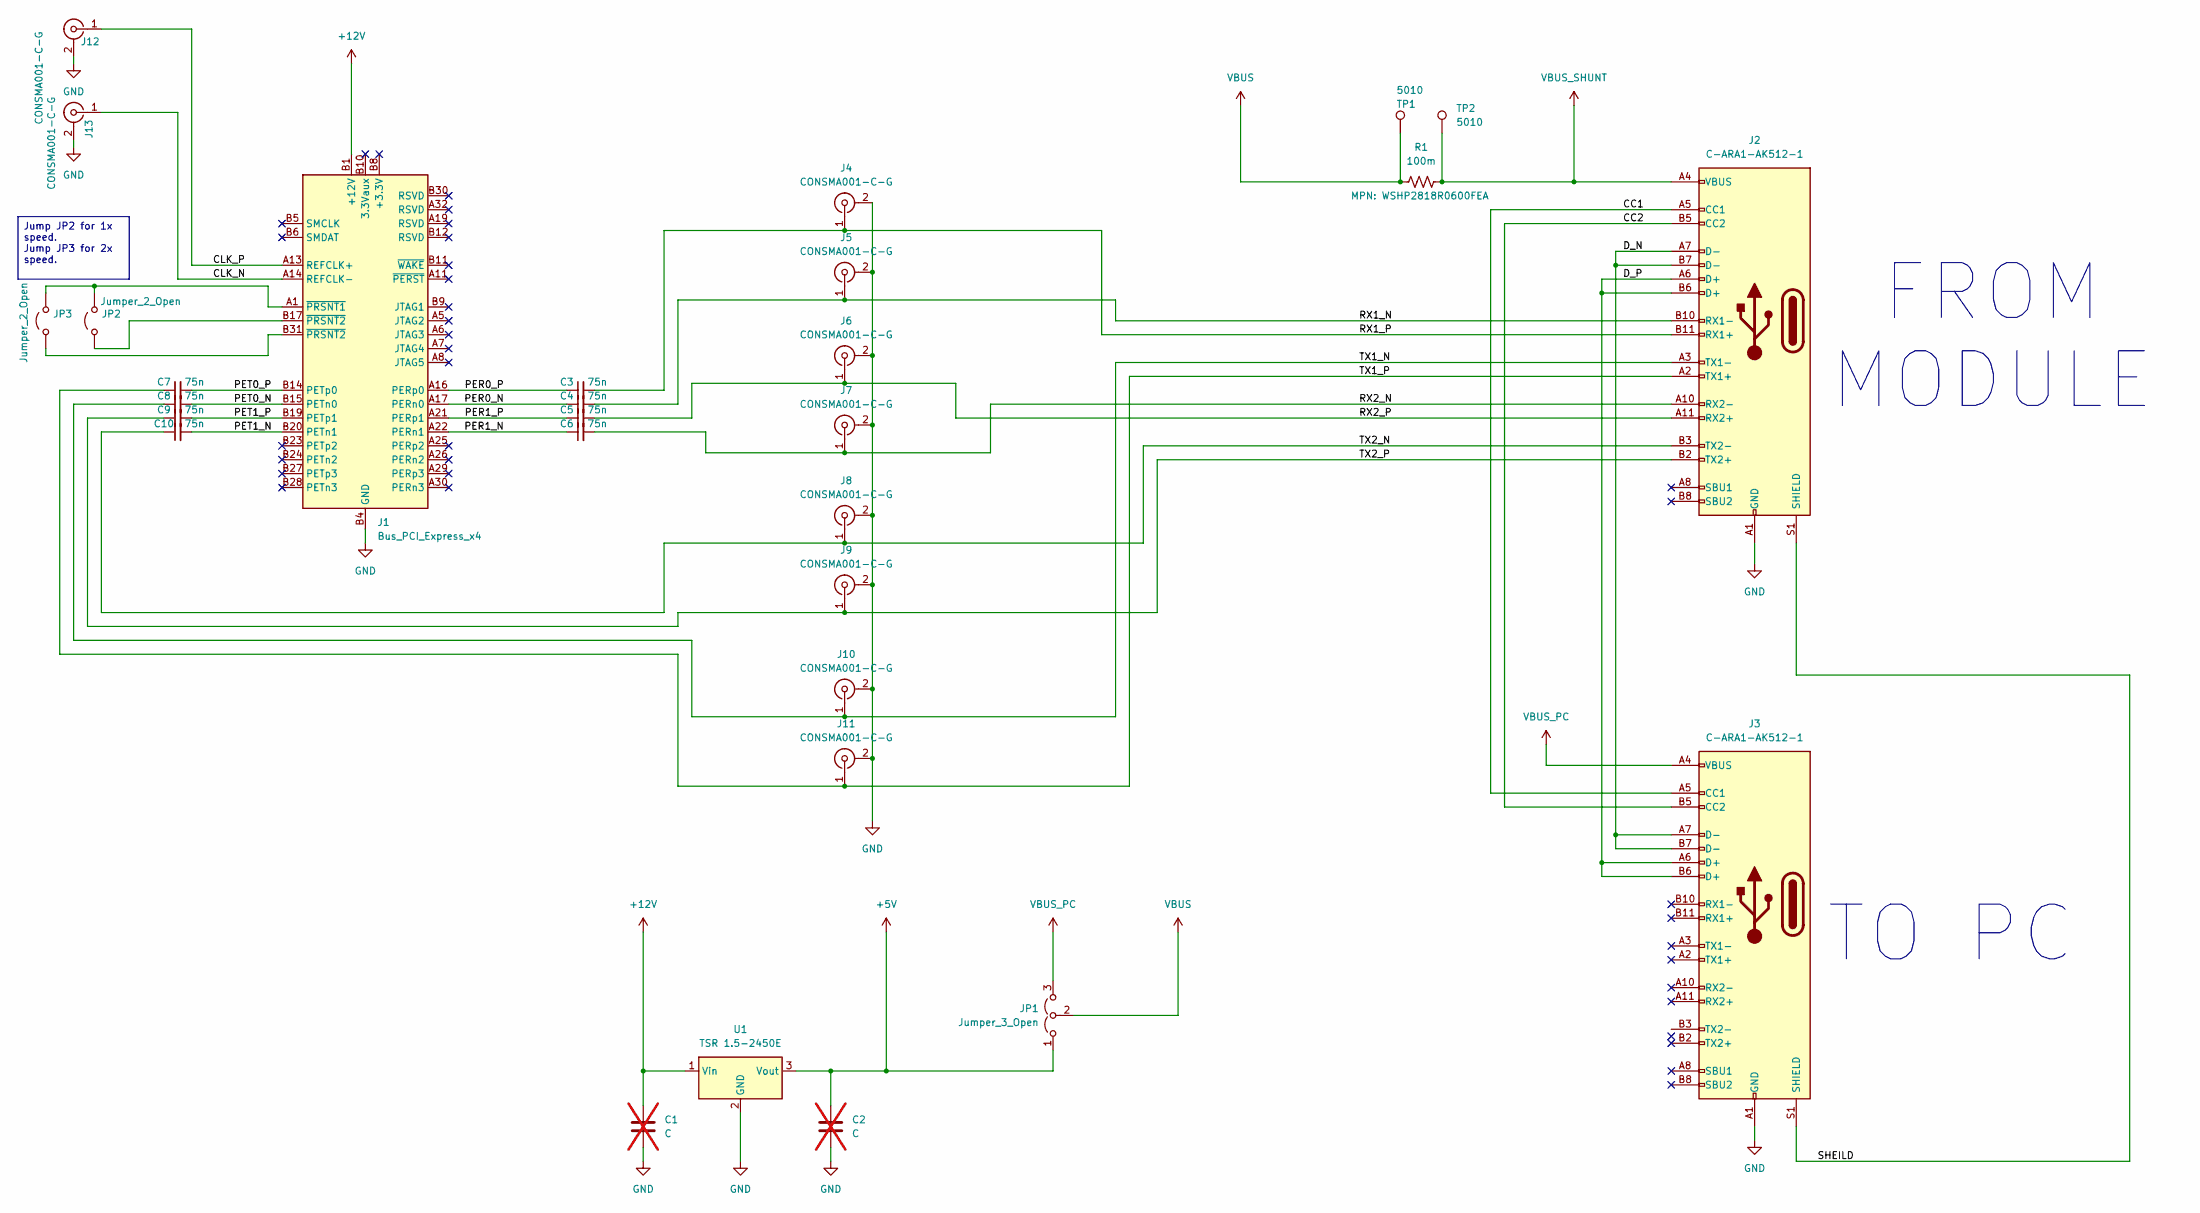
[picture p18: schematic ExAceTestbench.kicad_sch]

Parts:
C1, C2: C; C_1206_3216Metric; not fitted
C3, C4, C5, C6, C7, C8, C9, C10: 75n; C_0402_1005Metric
J1: Bus_PCI_Express_x4; BUS_PCIexpress_x4
J2, J3: C-ARA1-AK512-1; USB_C_Receptacle_CNCTech_C-ARA1-AK51X; MPN C-ARA1-AK512-1
J4, J5, J6, J7, J8, J9, J10, J11, J12, J13: CONSMA001-C-G; SMA_Amphenol_901-144_Vertical; MPN CONSMA001-C-G
JP1: Jumper_3_Open; PinHeader_1x03_P2.54mm_Vertical
JP2, JP3: Jumper_2_Open; PinHeader_1x02_P2.54mm_Vertical
R1: 100m; 2818; MPN WSHP2818R0600FEA
TP1, TP2: 5010; TestPoint_Keystone_5010-5014_Multipurpose; MPN 5010
U1: TSR 1.5-2450E; Converter_DCDC_TRACO_TSR-1_THT

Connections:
+5V: C2.1, JP1.1 (A), U1.3 (Vout)
+12V: C1.1, J1.A2 (+12V), J1.A3 (+12V), J1.B1 (+12V), J1.B2 (+12V), J1.B3 (+12V), U1.1 (Vin)
/CC1: J2.A5 (CC1), J3.A5 (CC1)
/CC2: J2.B5 (CC2), J3.B5 (CC2)
/CLK_N: J1.A14 (REFCLK-), J13.1 (In)
/CLK_P: J1.A13 (REFCLK+), J12.1 (In)
/D_N: J2.A7 (D-), J2.B7 (D-), J3.A7 (D-), J3.B7 (D-)
/D_P: J2.A6 (D+), J2.B6 (D+), J3.A6 (D+), J3.B6 (D+)
/PER0_N: C4.1, J1.A17 (PERn0)
/PER0_P: C3.1, J1.A16 (PERp0)
/PER1_N: C6.1, J1.A22 (PERn1)
/PER1_P: C5.1, J1.A21 (PERp1)
/PET0_N: C8.2, J1.B15 (PETn0)
/PET0_P: C7.2, J1.B14 (PETp0)
/PET1_N: C10.2, J1.B20 (PETn1)
/PET1_P: C9.2, J1.B19 (PETp1)
/RX1_N: C4.2, J2.B10 (RX1-), J5.1 (In)
/RX1_P: C3.2, J2.B11 (RX1+), J4.1 (In)
/RX2_N: C6.2, J2.A10 (RX2-), J7.1 (In)
/RX2_P: C5.2, J2.A11 (RX2+), J6.1 (In)
/SHEILD: J2.S1 (SHIELD), J3.S1 (SHIELD)
/TX1_N: C8.1, J2.A3 (TX1-), J10.1 (In)
/TX1_P: C7.1, J2.A2 (TX1+), J11.1 (In)
/TX2_N: C10.1, J2.B3 (TX2-), J8.1 (In)
/TX2_P: C9.1, J2.B2 (TX2+), J9.1 (In)
GND: C1.2, C2.2, J1.A4 (GND), J1.A12 (GND), J1.A15 (GND), J1.A18 (GND), J1.A20 (GND), J1.A23 (GND), J1.A24 (GND), J1.A27 (GND), J1.A28 (GND), J1.A31 (GND), J1.B4 (GND), J1.B7 (GND), J1.B13 (GND), J1.B16 (GND), J1.B18 (GND), J1.B21 (GND), J1.B22 (GND), J1.B25 (GND), J1.B26 (GND), J1.B29 (GND), J1.B32 (GND), J2.A1 (GND), J2.A12 (GND), J2.B1 (GND), J2.B12 (GND), J3.A1 (GND), J3.A12 (GND), J3.B1 (GND), J3.B12 (GND), J4.2 (Ext), J5.2 (Ext), J6.2 (Ext), J7.2 (Ext), J8.2 (Ext), J9.2 (Ext), J10.2 (Ext), J11.2 (Ext), J12.2 (Ext), J13.2 (Ext), U1.2 (GND)
unnamed: J1.A1 (~PRSNT1), JP2.2 (B), JP3.2 (B)
unnamed: J1.B17 (~PRSNT2), JP2.1 (A)
unnamed: J1.B31 (~PRSNT2), JP3.1 (A)
VBUS: JP1.2 (C), R1.1, TP1.1
VBUS_PC: J3.A4 (VBUS), J3.A9 (VBUS), J3.B4 (VBUS), J3.B9 (VBUS), JP1.3 (B)
VBUS_SHUNT: J2.A4 (VBUS), J2.A9 (VBUS), J2.B4 (VBUS), J2.B9 (VBUS), R1.2, TP2.1

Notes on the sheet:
FROM MODULE
TO PC
Jump JP2 for 1x speed. Jump JP3 for 2x speed.

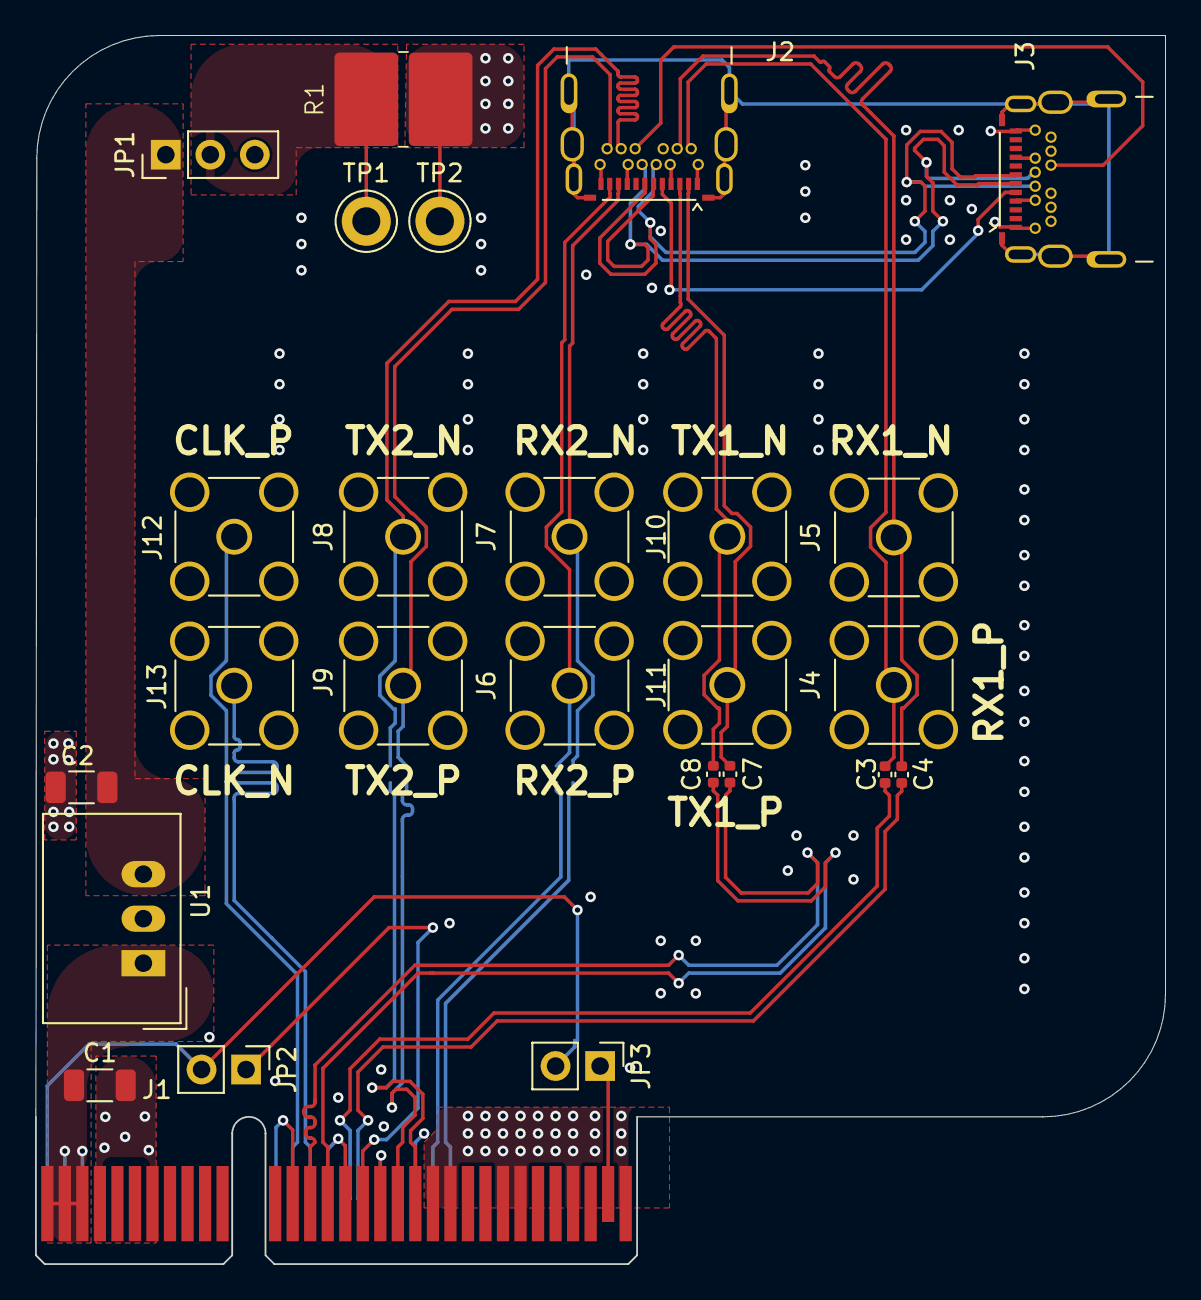
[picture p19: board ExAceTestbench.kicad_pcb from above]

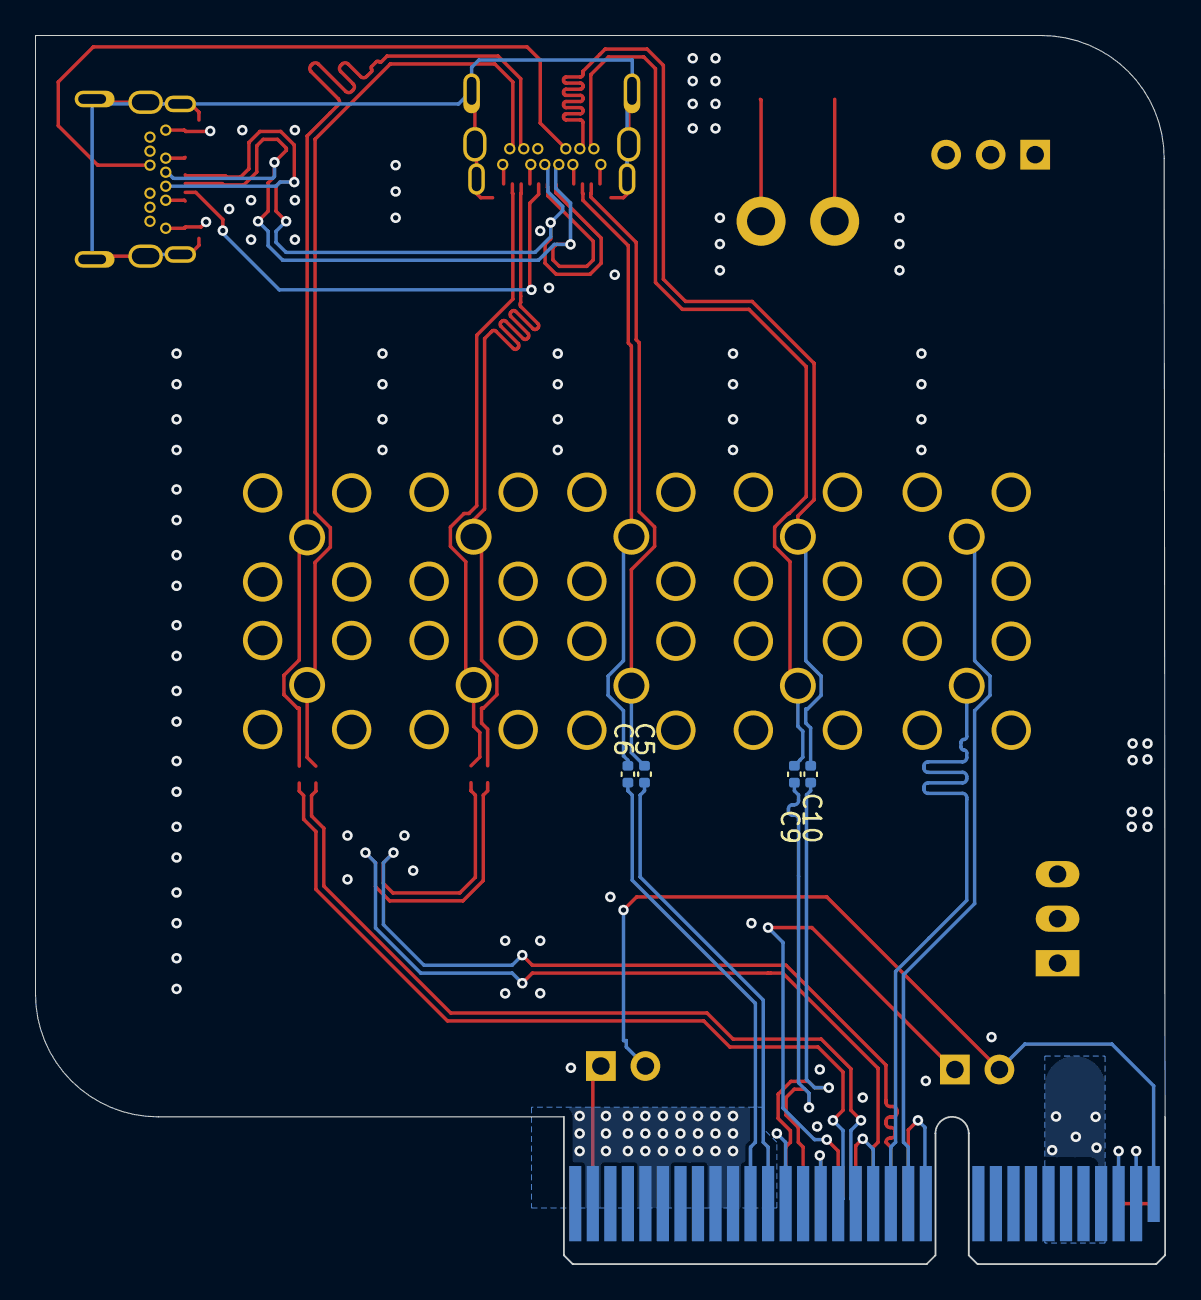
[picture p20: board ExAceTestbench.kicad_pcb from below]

Board: 4 copper layers, 64.5 x 70.1 mm, 30 parts (4 on the bottom side), 32 nets.

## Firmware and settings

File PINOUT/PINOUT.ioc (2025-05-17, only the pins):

Mcu.UserName=STM32L422RBIx
PA1.GPIO_Label=FPGA_RST
PA1.Signal=GPIO_Output
PA11.Signal=USB_DM
PA12.Signal=USB_DP
PA2.Signal=QUADSPI_BK1_NCS
PA3.Signal=QUADSPI_CLK
PA6.Signal=QUADSPI_BK1_IO3
PA7.Signal=QUADSPI_BK1_IO2
PA8.Signal=RCC_MCO
PB0.Signal=QUADSPI_BK1_IO1
PB1.Signal=QUADSPI_BK1_IO0
PB10.Signal=LPUART1_RX
PB11.Signal=LPUART1_TX
PB12.GPIO_Label=USB_PU
PB12.Signal=GPIO_Input
PB13.Signal=I2C2_SCL
PB14.Signal=I2C2_SDA
PB9.GPIO_Label=CFG3
PB9.Signal=GPIO_Output

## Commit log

2025-03-15 first routing
    [5024302030.stp, Expansion_Card_Retrofit.kicad_pcb, Expansion_Card_Retrofit.kicad_sch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]
2025-03-21 Layout and add sensor
    [Controled_Impedance.xlsx, Expansion_Card_Retrofit.kicad_pcb, Expansion_Card_Retrofit.kicad_sch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]
2025-03-29 update on layout first drc done
    [1054440011.stp, 5024302030.stp, ExpansionCard_SelfTapping.stl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]
2025-04-28 start to switch to stm32
    [Expansion_Card_Retrofit-B_Cu.gbl, Expansion_Card_Retrofit-B_Fab.gbr, Expansion_Card_Retrofit-B_Mask.gbs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]
2025-04-29 draft layout
    [Expansion_Card_Retrofit.kicad_pcb, Expansion_Card_Retrofit.kicad_sch, KXT_331_LHS.STEP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]
2025-05-03 testbench done
    [ExAceTestbench.kicad_pcb, ExAceTestbench.kicad_sch, Expansion_Card_Retrofit.kicad_pcb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]
2025-05-06 fixed diff pair
    [Expansion_Card_Retrofit.kicad_pcb, Expansion_Card_Retrofit.kicad_sch, POWER.kicad_sch]
2025-05-17 remove some unused files
    [1054440011.stp, 5024302030.stp, S3A2505-100.000-L-X1-R.step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]
2025-05-21 add readme
    [Expansion_Card_Retrofit.kicad_pcb, Expansion_Card_Retrofit.kicad_sch, POWER.kicad_sch]
2025-05-21 fix wording and remove unused models
    [5024302030.stp, RP2350_QFN60.step]
2025-05-24 add stackup to readme
    [Expansion_Card_Retrofit.kicad_sch]
2025-06-04 fix a clearance issue
    [Expansion_Card_Retrofit-B_Cu.gbl, Expansion_Card_Retrofit-B_Fab.gbr, Expansion_Card_Retrofit-B_Mask.gbs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]
2025-06-04 fix clearance on R4
    [Expansion_Card_Retrofit.kicad_pcb]
